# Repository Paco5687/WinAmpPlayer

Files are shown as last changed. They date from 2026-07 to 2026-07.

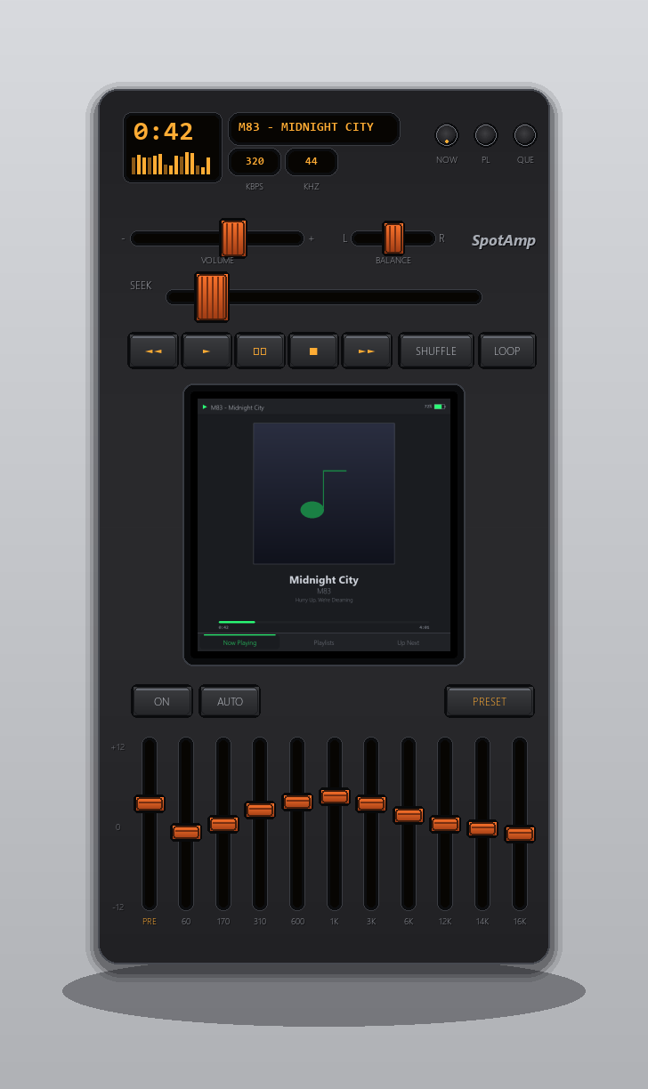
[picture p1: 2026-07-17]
docs/images/product-render-compact.png

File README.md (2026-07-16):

# WinAmp · Physical Edition

A handheld, book-sized (≈8″ × 5″ × 1″) physical Spotify player styled after the
classic WinAmp interface. Color LCD touchscreen for the playlist and album art;
everything else is **real hardware** — buttons, pots, and **motorized faders**
for a graphic EQ plus volume and a seek fader that physically follows the song.

Inspired by [Eslam Mohamed's modular WinAmp concept](https://www.yankodesign.com/2024/04/27/modular-media-player-concept-brings-iconic-winamp-design-to-the-physical-world/)
— but built as a single integrated unit, and actually real.

> *It really whips the llama's ass.*

**Open source (MIT).** Built on a **Raspberry Pi 4 B**. Code, full parts list, and
3D models are being published so you can build your own — see the
**[Wiki](https://github.com/Paco5687/WinAmpPlayer/wiki)** and
[CONTRIBUTING.md](CONTRIBUTING.md).

## Architecture at a glance

Two brains, because Linux is bad at real-time motor control and a microcontroller
is great at it:

```
        ┌───────────────────────────┐        USB serial        ┌──────────────────────┐
        │     Raspberry Pi 4 B       │◀───────(ASCII)──────────▶│  RP2040 (Pico)       │
        │                            │                          │                      │
        │  go-librespot ─▶ ALSA EQ ─▶│─▶ I2S DAC ─▶ 🎧          │  buttons / pots      │
        │        │            ▲      │                          │  encoders            │
        │  Spotify Web API    │      │   FADER <id> <pos> ──────▶  motorized faders    │
        │        │            │      │                          │   (PID position loop)│
        │  Pygame UI (this) ──┘      │◀──── EV FADER/BTN/TOUCH ──│  ← wiper ADCs (mux)  │
        └───────────────────────────┘                          └──────────────────────┘
              color LCD touchscreen
```

- **[`pi/`](pi/)** — the Python/Pygame player app. Runs **fully mocked on a
  laptop today** (no hardware, no Spotify account needed). This is where the UI
  and app logic live.
- **[`firmware/`](firmware/)** — the RP2040 firmware: reads controls, runs the
  closed-loop control for the motorized faders, speaks the serial protocol.
- **[`hardware/`](hardware/)** — bill of materials, wiring, enclosure notes.
- **[`docs/`](docs/)** — [architecture](docs/architecture.md) and the
  [serial protocol spec](docs/serial-protocol.md).

## Try it right now (no hardware)

```bash
cd pi
pip install -r requirements.txt
python -m winamp_player
```

A square (720×720) window opens with the device's **multi-view UI** — the same
screen that runs on the HyperPixel: **Now Playing**, **Playlists**, and **Up Next**.
Switch views with the bottom tabs (or keys `1`/`2`/`3`). Transport/EQ/faders are
physical hardware on the real device, not on the screen.

Keys: `1/2/3` switch views · `space` play/pause · `←/→` prev/next · `↑/↓` volume · `s` stop · `q` quit.

Requires **Python 3.11+** (uses `tomllib`).

## Status

**Standalone on a Pi 4 B and playing** — full [project board](https://github.com/users/Paco5687/projects/4).

Done:
- [x] Desktop mock app end-to-end (UI, Spotify Web API browse, playback, queue)
- [x] **go-librespot** on the Pi — standalone audio, no phone (see [docs/pi-bringup.md](docs/pi-bringup.md))
- [x] App running on the device's screen (portrait), controlling the local player

Next up:
- [ ] **Central screen redesign** — HyperPixel 4.0 Square + compact multi-view UI (now playing / playlists / queue) with physical view buttons
- [ ] RP2040 firmware: buttons, pots, encoders, motorized-fader PID
- [ ] ALSA software EQ + real FFT spectrum
- [ ] Power (USB-C UPS, battery via RP2040) and enclosure CAD

See [docs/pi-bringup.md](docs/pi-bringup.md) and per-directory READMEs for details.

## The honest hard parts

- **Spotify needs Premium + go-librespot.** There's no official "play a playlist
  on a Pi" API. go-librespot is a full Spotify client that runs on the Pi and
  authenticates **standalone — no phone** (one-time OAuth, then cached). See
  [docs/spotify-setup.md](docs/spotify-setup.md).
- **Motorized faders are the cost/complexity center.** A full motorized EQ +
  volume + seek is ~10 motorized faders (~$180+) plus motor drivers, position
  ADCs (via a mux), and a PID loop. A 10-band EQ won't physically fit a 5″ width,
  so this build uses a **7-band** EQ. See [hardware/BOM.md](hardware/BOM.md).
- **Spotify exposes no EQ**, so the graphic EQ is a software EQ in the Pi's ALSA
  pipeline, applied to go-librespot's output before the DAC.

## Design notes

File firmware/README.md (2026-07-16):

# Firmware (RP2040 / Raspberry Pi Pico)

Owns all physical I/O and the real-time motor loops for the motorized faders.
Talks to the Pi over USB serial using the [serial protocol](../docs/serial-protocol.md).

## Build

Uses [PlatformIO](https://platformio.org/) with the Arduino core for RP2040
(`earlephilhower/arduino-pico`):

```bash
cd firmware
pio run                 # build
pio run -t upload       # flash (hold BOOTSEL on first flash, or use the reset)
pio device monitor      # watch the serial link
```

## What it does

- Reads buttons (via MCP23017), encoders, the balance pot, and all fader wiper
  positions (through a CD74HC4067 analog mux, since the Pico has only 3 ADC
  channels).
- Runs a per-fader **PID loop** at ~1 kHz driving each motorized fader toward the
  target the Pi last sent (`FADER <id> <pos>`), and yields the motor while the
  user is touching that fader (MPR121 touch electrodes).
- Drives the **amber OLED readout** (SSD1322 over SPI) from `DISP` commands the
  Pi streams (title / time / stream info).
- Emits `EV …` events upstream (button presses, user fader moves, touch, encoders).

> **I/O architecture:** motor PWM goes through **2× PCA9685** and buttons/touch
> through **MCP23017/MPR121**, all on one I2C bus — direct-wiring doesn't fit the
> Pico's 26 GPIO. Full pin budget in [../hardware/wiring.md](../hardware/wiring.md).
> The `main.cpp` skeleton still drives one fader on direct pins for bring-up;
> switch to the PCA9685 when scaling past one.

The firmware is **fully built out** (desk-written 2026-07-16, compiles clean,
untested on hardware): every I2C device driver, the OLED readout with the `DISP`
marquee, buttons/encoders/touch/battery events, and the per-fader PID against
the PCA9685. `src/config.h` holds all pins, addresses, and tuning constants —
including **feature flags** (`HAS_PCA9685`, `HAS_OLED`, …) so bench bring-up can
enable one subsystem at a time. A missing I2C board logs `... MISSING` and
degrades instead of hanging.

## Bring-up order (with the full firmware)

1. Flash with **all `HAS_*` flags off except none needed** — `PING`→`PONG` over
   USB proves the link (`LOG winamp-fw ready`).
2. Enable `HAS_MCP23017` → press buttons, watch `EV BTN`. Encoders are always
   on (direct GPIO) — turn them, watch `EV ENC`.
3. Wire fader #1 (wiper → mux ch0, motor → PCA A ch0/1, touch → MPR121 e0);
   enable `HAS_PCA9685` + `HAS_MPR121`. Send `FADER 0 512` — tune `PID_KP/KD`
   and `PWM_MIN_MOVE` (stiction floor) in `config.h` until it glides.
4. Enable `HAS_OLED` — the Pi's `DISP` stream should show time + title.
5. Enable `HAS_TPA2016` + `HAS_MAX17040` — battery `EV BAT` every 5 s, jack
   insert mutes the amp.
6. Scale to all 10 faders.

⚠️ Safety built in: PCA9685 **/OE is held high (motors disabled) until the
firmware has zeroed all channels** — no fader slam on boot.

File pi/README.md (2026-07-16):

# Pi app — `winamp_player`

The Python/Pygame application: the WinAmp-style UI, Spotify control, and the
bridge to the microcontroller. Runs **fully mocked on a laptop** so you can build
the UI with no hardware and no Spotify account.

## Run (mock mode — default)

```bash
cd pi
pip install -r requirements.txt   # pygame is all you need for mock mode
python -m winamp_player
```

Requires **Python 3.11+** (uses the stdlib `tomllib`).

A square (720×720) **multi-view** window opens — the device screen: **Now Playing**,
**Playlists**, **Up Next**. On the real device these views are switched by dedicated
physical buttons; transport/EQ/faders are hardware, not on screen.

**Controls in the window (dev):**

| Input | Action |
|---|---|
| Tabs / `1` `2` `3` / `Tab` | switch view (Now Playing / Playlists / Up Next) |
| Tap a playlist row | open + play that playlist |
| `space` | play/pause |
| `←` / `→` | prev / next |
| `↑` / `↓` | volume |
| `s` | stop · `q` / `Esc` quit |

## Connect Spotify (Web API — playlists & album art)

No website or hosting needed — it uses a **loopback redirect + PKCE**.

1. Create an app at https://developer.spotify.com/dashboard.
2. Add this **exact** redirect URI (Spotify banned `localhost`; loopback HTTP is fine):
   ```
   http://127.0.0.1:8888/callback
   ```
3. Put the app's **Client ID** in `config.toml` as `spotify_client_id` (no secret needed).
4. Authorize once:
   ```bash
   python -m winamp_player.authorize
   ```
   A browser opens, you approve, and a refresh token is cached to
   `pi/spotify_token.json` (gitignored). The device refreshes tokens forever after that.

`go-librespot` (the audio playback) authenticates **separately and standalone** —
using its own one-time **interactive OAuth** login (no phone required; a phone via
Spotify Connect is only an optional alternative). It needs Premium. See
[../docs/spotify-setup.md](../docs/spotify-setup.md) for both one-time logins.

## Run against real hardware

Copy `config.example.toml` → `config.toml` and set:

```toml
backend  = "librespot"      # needs a running go-librespot + Spotify Premium
controls = "serial"         # needs the RP2040 flashed and connected
serial_port = "/dev/ttyACM0"
fullscreen = true           # on the device LCD
```

`requests` and `pyserial` (in `requirements.txt`) are only needed for real
hardware; they're imported lazily so mock mode doesn't require them.

## Layout

```
winamp_player/
├── __main__.py      # python -m winamp_player
├── app.py           # main loop, action routing, MOTOR SYNC
├── config.py        # config.toml loader (zero-config defaults)
├── models.py        # PlayerState / Track — the source of truth
├── spotify.py       # MockPlayer + LibrespotPlayer behind PlayerBackend
├── controls.py      # serial protocol + MockControls / SerialControls
└── ui/
    ├── skin.py      # palette + portrait layout rectangles
    └── display.py   # rendering + mouse/touch -> actions
```

See [../docs/architecture.md](../docs/architecture.md) for how it all fits.

## Playlist browser

Once authorized (above), the touchscreen opens on **your real Spotify
playlists** with album-art thumbnails (loaded async so the UI never blocks).
Tap a playlist → tap a track → it plays. The **eject** button (or `b`) returns
to the library. Without a token it falls back to a demo playlist.

### Playing followed playlists (`backend = "webapi"`)

Spotify Dev Mode can't *read the track list* of playlists you don't own, but it
**can play them**. So there are two playback modes (set `backend` in `config.toml`):

| `backend` | Owned playlists | Followed / editorial playlists | Audio |
|---|---|---|---|
| `mock` (default) | tracklist + simulated playback | flagged "dev-mode locked" | none (simulated) |
| `webapi` | tracklist + **real playback** | **plays** (now-playing view, no tracklist) | real, on an active device |

To use `webapi` **now**, on your laptop:
1. Set `backend = "webapi"` in `config.toml`.
2. **Open the Spotify desktop or phone app** (it becomes the "active device" to play on).
3. Run the app. Owned playlists play with a tracklist; followed playlists show a
   **now-playing** card (art, title, progress) mirrored from the real player.

On the Pi, the "active device" becomes **go-librespot** instead of the Spotify
app — same code path, no phone. If you see *"No active Spotify device,"* nothing
is available to play on yet.

### "Up Next" tracklist

In `webapi` mode the now-playing view shows an **UP NEXT** list from the Spotify
**playback queue** (`GET /me/player/queue`). This gives you a tracklist for
*anything* playing — including followed/editorial playlists whose tracks Dev Mode
won't let us read directly, and whatever's playing on another device. It shows
what's coming up (not the full playlist history).

## Notes / TODO

- **Album art** is now real (fetched + cached from the Web API in `images.py`).
  Placeholder gradient shows only until each image finishes downloading.
- **Spectrum** is simulated when no audio tap is present; on the Pi, feed real
  FFT magnitudes into `PlayerState.spectrum`.
- **EQ** currently just stores band gains; the ALSA software-EQ pipeline that
  applies them is milestone M5 (see architecture roadmap).

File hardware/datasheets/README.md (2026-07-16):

# Datasheets

Run `bash fetch.sh` in this directory to download every part's datasheet /
mechanical drawing (~26 MB). **The PDFs are gitignored** — they're manufacturer
copyright, so the repo ships the script + this index instead of the files.

## Index + key facts for case design

| File | Part | Key mechanical / electrical facts |
|---|---|---|
| `alps-rs60n-motorized-fader.pdf` | ALPS RS60N11M9A0F | ⚠️ **Body 18.5 mm wide** (min pitch ~19–20 mm), **26 mm deep below panel**, mounting 2× M3, lever 8.2 mm above panel, motor **rated 10 V DC / ≤800 mA**, travel 60 mm, touch-sense track. See [../enclosure.md](../enclosure.md) for the layout consequences. |
| `pca9685-pwm-driver.pdf` | NXP PCA9685 | 16-ch 12-bit PWM, I2C (up to 62 addrs), ~24–1526 Hz PWM |
| `mpr121-cap-touch.pdf` | NXP MPR121 | 12 electrodes, I2C 0x5A–0x5D |
| `mcp23017-gpio-expander.pdf` | Microchip MCP23017 | 16 GPIO, I2C 0x20–0x27, interrupt outs |
| `cd74hc4067-mux.pdf` | TI CD74HC4067 | 16:1 analog mux, ~70 Ω on-resistance |
| `drv8833-motor-driver.pdf` | TI DRV8833 | dual H-bridge, 2.7–10.8 V, 1.5 A RMS/bridge |
| `tpa2016-speaker-amp.pdf` | TI TPA2016D2 | stereo Class-D 2.8 W@4Ω/5 V, I2C 0x58, AGC, shutdown |
| `ws2812b-led.pdf` | WS2812B | 800 kHz single-wire, 5 V |
| `pico-datasheet.pdf` / `pico-pinout.pdf` | Raspberry Pi Pico | board 51 × 21 mm, pin functions |
| `pi4-mechanical-drawing.pdf` | Pi 4 B | board 85 × 56 mm, port + hole positions |
| `pi4-reduced-schematics.pdf` | Pi 4 B | connector-level schematics |
| `bourns-pec11-encoder.pdf` | Bourns PEC11 (= Adafruit 377) | panel hole ⌀7 mm, shaft dims |
| `ssd1322-oled-controller.pdf` | SSD1322 | controller registers/commands (firmware) |
| `nhd-3.12-25664-oled-module.pdf` | NHD-3.12-25664UCY2 | module ≈ 88 × 27.8 mm (verify drawing page), 4-wire SPI |

## HTML-only references (no stable PDF)

- **Geekworm X728**: https://wiki.geekworm.com/X728 — HAT form (~85 × 56 mm) +
  pogo/header stack height; schematic + safe-shutdown scripts on the wiki.
- **HyperPixel 4.0 Square**: https://shop.pimoroni.com/products/hyperpixel-4-square —
  ~85 × 85.5 × 12 mm per product page (verify before cutting the bezel).
- **ALPS 3D CAD (STEP)** for the fader is downloadable from the ALPS product page —
  grab it when starting CAD: https://tech.alpsalpine.com/e/products/detail/RS60N11M9A0F/

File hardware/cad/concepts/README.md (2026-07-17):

# Layout concepts (exploration — not the authoritative drawing)

**concept-e — CURRENT FRONT-RUNNER (185 × 295 mm)**: the owner's sketch at A's
proportions. **The screen is the centerpiece** (engraved accent frame, floated
in open space); quiet right strip (speaker grille + 2×2 pots); view-key stack
top-right; 6-button transport; LOOP/EQ/PRESET function row + encoders + balance;
full-width seek; **A's 8 faders unchanged**, spread at 21 mm pitch. Pure layout —
zero BOM/firmware/I/O change from A. Pending 1:1 paper test → replaces mainline.

**concept-d — the owner's sketch (220 × 280 mm)**: OLED top-left, **view-key
stack top-right**, 6-button transport row (+SHUF), full-width volume, function
row (LOOP/EQ/PRESET keys + encoders + balance), **screen left**, speaker grille
field + 2×2 pot cluster right, seek right-side (kept — the signature fader; the
sketch omitted it), and the **full 10-band + preamp EQ** across the bottom.
Current front-runner pending 1:1 paper test.

**concept-c — "the in-between" (220 × 280 mm)**: the vibe-keeper. Screen stays
**centered** (classic stacked-module composition), full **10-band EQ + preamp**,
and **symmetric stereo grille fields** flanking the screen (L/R where stereo
wants them). No pot column. Button columns cleared of the HyperPixel board edge
(3D check). Owner feedback path: A = vibe but 7-band · B = 10-band but vibe lost
· **C = both**.

**concept-b** (225 × 280 mm): screen offset left, right-hand pot column
(HP-vol / brightness / 2 assignable), one large speaker-grille field, and the
**full classic 10-band EQ + preamp** (11 motorized faders). Generated from a
variant of [`../generate_panel.py`](../generate_panel.py); if chosen, the
variant becomes the main generator's parameters and this folder is cleaned up.

I/O check at 11 faders: 22/32 PCA9685 PWM · 11/12 MPR121 electrodes · 14/16 mux
channels — fits the existing architecture. Cost delta ≈ +$65–70.

Print the SVG at 100 % scale for the paper test (same as the main panel).

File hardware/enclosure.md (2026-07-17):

# Enclosure design notes

The case will be **3D-printed for the prototype** and, if it earns it,
**CNC-machined in anodized aluminum** for the final build. Every enclosure
decision must work for **both** processes — design for machining from day one,
print the same geometry.

## ⚠️ Findings from the real datasheets (2026-07-16)

Reading the ALPS RS60N11M9A0F drawing (see [datasheets/](datasheets/)) surfaced
three facts that change the body:

| Finding | Consequence |
|---|---|
| Fader body is **18.5 mm wide** → min pitch ~19–20 mm | An 8-fader bank needs **~155 mm**, but the panel is 127 mm. **The 7-band + preamp bank does not fit a 5″ width.** Options below. |
| Fader is **26 mm deep below the panel** | Body thickness grows from 25 mm to **~32 mm (1.25″)** (panel + 26 + wiring clearance), or the fader zone gets a raised rear bulge. |
| Fader motor rated **10 V / ≤800 mA** | On our 5 V rail the slew is slower/weaker (workable, common in DIY). Optional: a small 9 V boost for the motor rail. Bench-test with fader #1 before deciding. |
| **Fader body is ~106.5 mm LONG (M3 mounts 80 mm apart)** — found drawing the DXF | A *vertical* EQ fader needs ~110 mm of panel height, not the ~66 mm sketched earlier. The honest full stack (top module + volume + 73 mm screen + seek + EQ bank) sets the panel at **175 × 280 mm (6.9″ × 11″)** — which matches the Yanko render's real proportions. The laid-out proof: [cad/front-panel.dxf](cad/). |

### EQ-bank width options (decision pending)

| Option | Panel math | Trade-off |
|---|---|---|
| **A. Widen the body to ~165 mm (6.5″)** | 8 × 20 = 160 ✓ | keeps all 7 bands + preamp motorized; body is no longer "small book" |
| **B. 5 bands + preamp** | 6 × 20 = 120 ✓ fits 127 | fewer bands; protocol/firmware are per-band so it's a config change |
| **C. Reduced build** (motorized volume + seek only, slim non-motorized pots for EQ) | narrow pots ~10 mm pitch ✓ | loses the animated-EQ showpiece |

> **Current direction (2026-07-17, pending 1:1 print approval): the ONE-MOTOR
> design — 127 × 246 × ~30 mm** (`cad/front-panel-final.*`). EQ/volume/balance
> use slim non-motorized pots (full classic PRE + 10-band bank fits the beloved
> 127 mm width); **seek keeps the single motorized RS60N** (song-tracking
> showpiece). Yanko-faithful details: 4 sculpted apertures over the one OLED,
> WinAmp stack order, ON/AUTO/PRESET EQ header, ribbed caps, recessed wells.
> Electronics collapse: no PCA9685s, 1× DRV8833, ~−$220. The earlier 175 × 280
> all-motorized drawing (`cad/front-panel.*`) is superseded on approval.

## Design-for-machining rules (apply from the first CAD sketch)

1. **Two flat-dominant halves**: front panel (all cutouts) + rear tray (cavity).
   Both machinable from plate stock on a 3-axis mill; both printable flat.
2. **Internal corner radii ≥ 2 mm** everywhere a cutter must reach (an end mill
   can't cut a sharp inside corner). Exterior corners can be sharp or chamfered.
3. **No snap-fits, no living hinges, no print-in-place** — those are FDM-only.
   Fasten with **machine screws from the rear** into bosses: heat-set inserts in
   the printed version, **drilled + tapped** in aluminum (M3, ≥6 mm thread).
4. **Wall thickness ≥ 2 mm** (aluminum) / ≥ 2.4 mm (FDM, 6 perimeters at 0.4 mm).
5. **Through-cutouts are cheap in both processes** (fader slots, screen window,
   button holes, OLED window). **Deep pockets** with small tools are expensive —
   keep pocket depth ≤ 4× tool diameter where possible.
6. **Anodizing allowances**: type II adds ~5–10 µm/surface (negligible), but
   **mask or re-tap threads after anodizing** (anodized threads gall);
   bead-blast before anodize for the matte look. Black or clear both look right;
   colored fill on engraved labels is an option (engrave → anodize → fill).
7. **Labels**: engrave (V-bit or laser) rather than print/silkscreen — works on
   both plastic and aluminum, and survives handling.
8. 📡 **Wi-Fi in an aluminum box does not work.** The Pi's antenna will be
   completely shielded. Plan one of:
   - a **plastic antenna window** (the screen bezel area can be polymer trim),
   - the **kickstand slot / speaker grille** doubling as an RF aperture near the
     Pi's antenna corner,
   - or an **external/relocated antenna** (Pi 4 antenna mod is invasive — prefer
     the window). The FDM prototype hides this problem; **test Wi-Fi with the
     aluminum rear tray fitted** before finalizing.
9. **Serviceability**: the fader bank should mount to the panel with its M3
   screws (per the ALPS drawing: 2× M3 per fader, mounting-hole pattern in the
   datasheet) so a failed fader is replaceable without disassembling the stack.
10. **Thermals**: Pi 4 + motor drivers in a sealed metal box is actually *good*
    (the case is the heatsink) — add a thermal pad from the Pi SoC to the rear
    tray in the aluminum version; the printed version needs vent slots instead.

## Reference dimensions for CAD

| Component | Envelope | Source |
|---|---|---|
| ALPS RS60N fader | 18.5 w × ~88 l × 26 mm below panel; lever +8.2 mm | datasheet drawing |
| HyperPixel 4.0 Square | ~85 × 85.5 × 12 mm | product page (verify) |
| Pi 4 B | 85 × 56 mm, holes 58 × 49 mm grid | `pi4-mechanical-drawing.pdf` |
| X728 UPS | HAT: 85 × 56 mm + 18650 holders | wiki.geekworm.com/X728 |
| Pico | 51 × 21 mm | `pico-datasheet.pdf` |
| OLED module | ≈ 88 × 27.8 mm | NHD spec (verify) |

## Speakers (added 2026-07-16 — standalone playback, headphones optional)

- **Drivers**: enclosed stereo pair, **70 × 30 × 17 mm each** (sealed backs — no
  custom acoustic chamber needed; they just bolt in). Fits the 32 mm depth.
- **Placement**: side edges of the top module firing outward, or flanking the
  screen — decide in CAD around the fader bank. Keep them away from the
  HyperPixel's rear (magnet clearance) and off the fader axis (vibration).
- **Grilles**: a drilled hole pattern looks *great* in anodized aluminum and is
  trivially machinable (≥1.5 mm holes, ≥2× diameter spacing). The FDM version
  prints the same pattern.
- **Headphone jack**: panel-mount switched TRS; insertion detect → MCP23017
  spare input → firmware mutes the TPA2016 over I2C. Jack near the bottom edge
  (cable hangs naturally when handheld).
- **Vibration**: mount drivers on thin foam gaskets so the aluminum panel
  doesn't buzz at volume.
- **Loudness upgrade slot (decided 2026-07-16)**: v1 ships the TPA2016; the CAD
  reserves space for a **MAX9744 (I2C, same bus) + 5→12 V boost** and grille area
  for ~2″/5 W drivers — the "small boombox" tier is a one-board swap after bench
  listening, no redesign.

## Kickstand (added 2026-07-17 — this is a DESKTOP device)

Per the concept's pop-out stand: the device lives on a desk, leaning back —
portable between rooms, not pocket-portable. Design decisions:

- **Type**: a flat **fold-out leg** hinged across the rear at the EQ-module
  height (lower third), Surface-style. In aluminum it's a machined flat plate —
  looks fantastic anodized; on the prototype it's the same geometry printed.
- **Hinges**: 2× **adjustable-torque (position-control) hinges** so the angle is
  continuously adjustable and holds anywhere (~$6–12 ea). Cheaper fallback: a
  plain piano hinge + a fold-out wire strut into detent notches (two angles).
- **Angle range**: 0° (flush) to ~40° open → face angle ~70–80° from the desk,
  matching the render and comfortable for fader reach + screen viewing.
- **Tip resistance — the physics that matters**: users *push* faders and buttons
  (1–3 N) near the top of a 280 mm face. The leg tip must land **well behind the
  center of mass** (leg ≥ 120 mm long), with **rubber feet on the leg tip and the
  body's bottom edge**. The battery pack (the heaviest part) mounts LOW in the
  body — it's the counterweight.
- **Flush stowage**: the rear tray gets a **recessed pocket** so the closed leg
  sits flush (machinable pocket — large corner radii; printable as-is). A small
  **magnet + steel disc** holds it closed with a satisfying snap.
- **Don't-block list**: the leg (open or closed) must not cover the USB-C charge
  port, the power switch, the thermal-pad zone (rear tray = heatsink), or the
  **Wi-Fi antenna window** — place the pocket accordingly in CAD.
- The rear tray + stand get their own generated drawing when we do the body CAD
  (the parametric generator extends to it — same source of truth as the panel).

## The OLED aperture cluster (how the "multiple displays" work)

One 256×64 OLED sits behind **four sculpted apertures** (time+spectrum window,
title strip, two kbps/kHz pills) — the panel mask turns one display into four.
Implementation notes:
- The apertures must land inside the OLED's **76.78 × 19.18 mm active area**;
  positions in `cad/generate_panel.py` are derived from it. Mask alignment
  tolerance ±0.5 mm — locate the OLED with pins/bosses, not adhesive guesswork.
- Put a **smoked/amber acrylic layer** (~1 mm) behind the apertures so off
  pixels vanish into black and the windows read as separate lit instruments.
- Firmware renders each element at fixed pixel regions matching the mask (the
  `DISP` data already carries everything; the region map is a table in
  `firmware/src/config.h` when formalized).

## The seek mechanism (owner's design, 2026-07-17): custom belt drive

Off-the-shelf motorized faders package the motor IN-LINE with the track — the
RS60N wastes 46 mm of length beyond its travel, and the 100 mm RSA0N is 146.5 mm
long. **We build the drive ourselves instead** (this is how flying faders work
internally anyway):

- **Panel part**: a slim **manual long-travel slide pot** (~85–90 mm travel,
  body ≤ 118 mm — VERIFY candidate part) → the slot spans ~70 % of the face at
  the 127 mm width. Wiper = position feedback (mux, as always); metal knob =
  touch electrode (MPR121).
- **Drive**: micro gearmotor (N20-class) + 2× GT2 16T pulleys + a GT2 belt loop
  behind the panel, with a printed clamp tying the belt to the fader lever — a
  miniature 3D-printer axis. Motor mounts beside/behind; envelope ~120 × 14 mm
  (REF box in the cut drawing).
- **Electronics/firmware unchanged**: DRV8833 + the existing PID loop drive it
  identically to a packaged motorized fader.
- ⚠️ **The critical detail — backdrivability**: the user must be able to grab
  the fader anytime. High-ratio gearmotors lock. Prototype in this order:
  (1) **slip-clutch pulley** — printed friction hub on the motor pulley (what
  ALPS does internally); (2) low-ratio (≤30:1) or coreless motor that
  backdrives freely; (3) touch-triggered release as backup. **Bench-prove the
  clutch before committing the panel.**
- Benefits: −$20 ALPS fader → +~$15 of motor/belt/pulleys, every mechanical
  part printable now and machinable later, and the seek slot finally matches
  the concept's proportions.

### Why output-side sensing (and not a servo indicator)

Considered and rejected (2026-07-17): a servo-driven progress pointer ("the
motor knows the position"). Three reasons the pot-on-the-knob topology wins:
1. **The pot measures the actual knob** — belt slip is cosmetic and
   self-correcting (PID drives until the *output* arrives). A servo knows only
   its motor-side pot; a loose linkage lies with no sensor to catch it.
2. **Touch-gating means motor motion can never seek the song** — position
   events only fire while the MPR121 senses a grab. The song clock lives in
   go-librespot; the fader follows it, not vice-versa.
3. **Servos aren't back-drivable** — grab-to-scrub (the whole point) dies.

**De-risk path**: the panel is identical with or without the motor — if the
slip-clutch prototype disappoints, v1 ships seek as a manual-scrub fader and
the belt drive lands in v1.1 with zero panel changes.

## Knobs & finish

- **Final build**: aluminum fader caps (T-bar or rectangular, for the ALPS 9-T
  lever) + knurled aluminum encoder knobs, anodized to match or contrast the body.
- **Prototype**: 3D-print the same knob geometry so the CAD is shared — print to
  fit, then order/machine the aluminum versions from the identical model.
- Fader caps must clear adjacent slots at 20 mm pitch — cap width ≤ 16 mm.

Grab the **ALPS STEP model** from the product page when CAD starts — it's the
part everything else packs around.

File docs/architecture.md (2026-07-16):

# Architecture

## Why two brains

The Pi runs Linux, which is non-deterministic under scheduling load — fine for
UI and networking, bad for a tight motor-control loop that has to run at a
steady ~1 kHz to keep motorized faders from oscillating. So:

- **Raspberry Pi** — Spotify client, audio pipeline, the LCD UI, high-level
  logic. Sends *targets* ("move volume fader to 72%").
- **RP2040 microcontroller** — soft-real-time I/O. Owns the PID loops that drive
  each motorized fader to its target, debounces buttons, reads pots/encoders,
  and streams events up to the Pi.

They talk over a simple newline-delimited ASCII protocol on USB serial. See
[serial-protocol.md](serial-protocol.md).

## Alternative platforms (future / v2)

The **[Arduino Uno Q](https://docs.arduino.cc/hardware/uno-q/)** is architecturally
this exact design on a single board: a Qualcomm Dragonwing QRB2210 (quad
Cortex-A53, runs Debian Linux) **plus** an STM32U585 (Cortex-M33) real-time MCU,
with an internal bridge — i.e. our "Pi brain + RP2040 brain" fused, plus eMMC.

We're **staying on Pi 4 B + RP2040 for v1** because: the Uno Q's MIPI-DSI display
and analog audio come out only via a separate carrier board; it's brand-new
(Oct 2025) with an unproven ecosystem/supply — risky for a build others must
reproduce; and we already have a working Pi stack. It's a strong **v2 candidate**
if its ecosystem matures — it could collapse both boards into one.

## Audio path

```
Spotify ──▶ go-librespot ──▶ ALSA (software graphic EQ) ──▶ USB DAC ──▶ switched 3.5mm jack
                                    ▲                  │                     │ (no plug)
                          EQ gains from faders         │              TPA2016 amp ──▶ internal
                                                       │             (I2C, RP2040 bus)  speakers
                                          audio tap ──▶ FFT ──▶ spectrum bars (UI)
```

> The DAC is **USB** (not a GPIO I2S HAT) because the HyperPixel display's DPI
> interface consumes all 40 GPIO pins, including I2S. The Pi's 3.5 mm jack works
> for bring-up. **Standalone playback** comes from internal enclosed speakers via
> a TPA2016 Class-D amp; inserting headphones mutes the amp (jack detect →
> firmware). External outputs are software: **Spotify Connect transfer** (Sonos &
> co. via the Web API — no audio plumbing) and **Bluetooth A2DP** from the Pi 4's
> onboard radio.

- **go-librespot** is a full Spotify client that streams and decodes audio
  directly (requires Premium). It authenticates **standalone via interactive
  OAuth** — a one-time browser login, then it reconnects on cached credentials
  forever, no phone. It exposes an HTTP + WebSocket API for transport and
  now-playing metadata. (Zeroconf/"pick it from a phone" is an optional mode we
  don't rely on.)
- The **graphic EQ is ours** — Spotify exposes no EQ over the API, so we insert a
  software EQ into the ALSA chain (e.g. an `ladspa`/`caps` multi-band plugin, or
  a custom filter). The motorized EQ faders set its band gains.
- A **loopback/monitor tap** feeds a small FFT so the spectrum analyzer reflects
  the actual audio, not a simulation. (In mock mode it's simulated.)

## The Pi app (`pi/winamp_player/`)

| Module | Responsibility |
|---|---|
| `models.py` | `PlayerState`, `Track` — the single source of truth the UI renders |
| `spotify.py` | `MockPlayer` (simulation), `WebApiPlayer` (drive any Connect device), `LibrespotPlayer` (the on-device player) behind one `PlayerBackend` interface |
| `spotify_web.py` / `spotify_auth.py` | Web API client (playlists, queue, control) + loopback-PKCE auth |
| `library.py` / `images.py` / `power.py` | Async playlist browsing, album-art cache, battery sources |
| `controls.py` | Serial protocol + `MockControls` / `SerialControls` |
| `ui/skin.py` | Palette + shared drawing helpers |
| `ui/screen.py` | Compact **multi-view** screen UI (Now Playing / Playlists / Queue) for the square LCD; turns touch/buttons into actions |
| `app.py` | Main loop, action routing, and **motor sync** |

### Motor sync — the signature trick

Every frame, `app._sync_motors()` computes where each motorized fader *should*
be from `PlayerState` (volume, seek progress, EQ band gains) and sends a
`FADER <id> <pos>` target — **unless the user is currently touching that fader**
(tracked via `EV TOUCH` events). So:

- Change the song → the **seek fader glides** to the new position and tracks it.
- Load an EQ preset → the **EQ faders physically animate** into the curve.
- Grab a fader → the motor yields; when you let go, it holds your value.

### Backend abstraction

`PlayerBackend` is a `Protocol`. `MockPlayer` advances a demo playlist with no
network so the entire UI is buildable on a laptop. `LibrespotPlayer` maps the
same methods onto go-librespot's local HTTP API (the on-device path);
`WebApiPlayer` drives any active Spotify Connect device through the Web API
(useful for laptop dev with real audio). Swap via `config.toml`.

## Central screen & UI direction

The device is **physical-first**: transport, EQ, and faders are hardware; the
screen is a small **square** LCD (**HyperPixel 4.0 Square, 720×720**) showing the
compact **multi-view** UI in `ui/screen.py` — one view at a time, switched by
**dedicated physical buttons** (ButtonId 9–11 in the serial protocol; on-screen
tabs and keys `1`/`2`/`3` in dev). v1 views: Now Playing, Playlist selector, Play
Queue (Search later). Playback control uses `backend = "librespot"`
(go-librespot's local API on :3678), so control stays on the Pi — no cloud
round-trip. The HyperPixel's DPI takes all GPIO, so audio → USB DAC and battery
sensing → RP2040 (see hardware/BOM.md).

## Deployment on the Pi

The full, tested procedure is **[pi-bringup.md](pi-bringup.md)**. In short:

1. `go-librespot` as a systemd service, authenticated once via interactive
   OAuth (standalone; see [spotify-setup.md](spotify-setup.md)).
2. HyperPixel 4.0 Square via the `vc4-kms-dpi-hyperpixel4sq` overlay; rotation
   done at the **compositor** level so touch follows the display.
3. The UI as a systemd **user** service (kiosk): boots straight into the app,
   fullscreen, cursor hidden (`deploy/winamp-kiosk.*`).
4. *(Phase 4)* ALSA EQ between librespot and the USB DAC.
5. *(Phase 5)* RP2040 flashed and enumerated at `/dev/ttyACM0`.

## Roadmap

Tracked live on the **[project board](https://github.com/users/Paco5687/projects/4)**
(milestones Phase 1–9 plus "UI Redesign & Central Screen"). Done so far: desktop
mock, Spotify integration (auth/browse/playback/queue), standalone audio on the
Pi, HyperPixel + kiosk autostart, the multi-view screen UI. Next up:
playlist-detail view + list scrolling, RP2040 physical controls, motorized
faders, software EQ + real spectrum, power/battery, enclosure.

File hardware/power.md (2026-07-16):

# Power & Battery Design

The unit is handheld, so it runs from an internal battery with a regulated 5 V
rail, safe charging, battery monitoring, and a clean shutdown that protects the
SD card. This document sizes the system, recommends a topology that's easy for
others to replicate, and lists the tradeoffs.

> Status: **design + placeholders.** Cell counts, runtimes, and part choices are
> engineering estimates — verify against the specific boards/cells you buy.

## 1. Power budget

Measured/typical draw on a **Raspberry Pi 4 B** based system. Motors are the
spiky load — they only draw current *while moving*, and our firmware cuts motor
power once a fader reaches its target, so the holding current is ~0.

| Subsystem | Typical | Peak | Notes |
|---|---:|---:|---|
| Pi 4 B (app + Wi-Fi + audio) | 4.5 W | 7 W | 4 cores + USB busy |
| 4″ DSI/HDMI LCD + backlight | 1.2 W | 2 W | backlight dominates |
| I2S DAC + headphones | 0.3 W | 0.5 W | |
| speaker amp (TPA2016, internal stereo) | 1 W | 3 W | standalone playback; ~0 W with headphones (amp muted) |
| RP2040 + mux + LEDs | 0.4 W | 1 W | |
| Motorized faders (10×) | ~0.2 W avg | **~12–15 W** | brief spikes when several move at once |
| **System** | **~6.5 W avg** | **~20 W peak** | design the 5 V rail for **5 A** headroom |

Key takeaways:
- **Average ≈ 6.5 W.** That's what sets runtime.
- **Peaks to ~20 W** for <1 s when a preset loads and many faders slew together.
  The 5 V regulator must survive that; handle it with **bulk capacitance
  (1000–2200 µF) at the motor-driver rail** so spikes come from the caps, not the
  battery/regulator.

## 2. Recommended topology

For a project other people will replicate, favor a **safe, off-the-shelf,
monitored** solution over a hand-rolled pack:

```
 18650 Li-ion cells ─▶ UPS/BMS HAT ─▶ regulated 5 V (up to 5 A) ─▶ Pi 4 B + everything
        ▲                   │  │
   USB-C / DC charge ───────┘  └── I2C: battery %, voltage, AC-loss  ─▶ Pi (safe shutdown + UI meter)
```

**Baseline:** a Pi-oriented UPS HAT that takes 18650 cells, outputs a solid
5 V/5 A, and reports battery state over I2C — e.g. **Geekworm X728** (2×18650,
auto power-on, AC-loss detect, documented safe-shutdown scripts) or **Waveshare
UPS HAT (B)** (2×18650, 5 V/5 A, INA219 fuel gauge). Verify current model numbers
and Pi 4 compatibility before buying — SKUs churn.

Why a HAT and not a bare pack: you get **cell protection, a proven 5 V boost
rated for Pi 4 peaks, charge management, and I2C monitoring** in one board — the
hard, safety-critical parts done right.

**Decision (v1): Geekworm X728.** Its MAX17040 fuel gauge (I2C `0x36`) is what
`pi/winamp_player/power.py` (`X728Battery`) reads for the on-screen meter and
safe shutdown; it has documented shutdown scripts and AC-loss detection. Waveshare
UPS HAT (B) remains a drop-in alternative — swap the reader class if you use it.
For more runtime, feed a larger 18650 pack (4–6 cells) to the board's terminals.

## 3. Sizing the battery ("large" is the goal)

18650 cell ≈ 3500 mAh @ 3.6 V ≈ **12.6 Wh** raw. After boost efficiency (~90 %)
and a safe depth-of-discharge (~85 %), figure **~9.6 Wh usable per cell**. At the
~6.5 W average:

| Pack | Raw Wh | Usable Wh | Runtime @6.5 W | Notes |
|---|---:|---:|---:|---|
| 2 × 18650 | 25 | ~19 | **~3 h** | fits a 2-cell HAT; thin |
| 4 × 18650 | 50 | ~38 | **~6 h** | sweet spot for "large" |
| 6 × 18650 | 76 | ~58 | **~9 h** | needs a bigger body/pack |
| 8 × 18650 | 101 | ~77 | **~12 h** | ⚠ **>100 Wh = no airline carry-on** |

For "large batteries," target **4–6 cells**. Options to get there:
- a **4-cell UPS board**, or
- an **external 2S2P / 2S3P 18650 pack** wired to the HAT's cell terminals, or
- higher-capacity cells (Molicel P28A, Samsung 35E, LG MJ1).

**Airline note:** keep total under **100 Wh** if the device should be flyable;
loose spare cells have their own carry-on rules.

## 4. Cells: 18650 vs LiPo pouch (a real form-factor tradeoff)

| | 18650 Li-ion | LiPo pouch |
|---|---|---|
| Shape | cylindrical Ø18 × 65 mm | flat, custom W×H, thin |
| Fit in a 1″ (25 mm) body | tight next to 60 mm faders | **better** — lies flat |
| Safety / replaceability | **excellent**, standardized, swappable | fussier, needs careful protection |
| Best for | a shareable, safe DIY build | a genuinely thin body |

**Recommendation:** default to **18650** for safety and replaceability (this is a
public build others will copy). If you insist on the slim 1″ book profile, a
**flat LiPo pouch + a good 2S BMS + 5 V buck** is mechanically nicer — but note
that **a large battery may push the body past 1″**; faders already want ~20 mm of
depth, and an 18-mm cell beside them is tight. Call this out in the enclosure CAD.

## 5. Charging

- Charge over the HAT's **USB-C (or DC) input**; the UPS provides pass-through so
  the unit can run while charging.
- Charge current is typically **1–2 A** — a big 4–6 cell pack will take **several
  hours** to fill. If that's annoying, pick a board/charger that supports higher
  charge current and use a capable USB-PD supply.
- **Never** charge unbalanced multi-cell packs without a balancing BMS.

## 6. Safe shutdown + battery UI (software milestone)

The UPS HAT exposes battery voltage / state-of-charge over **I2C**. The Pi should:
1. Read SoC periodically (INA219 / fuel gauge / board's ADC).
2. Show a **WinAmp-style battery meter** on the LCD (a natural fit for the skin).
3. On **low battery** (~5 %) or **AC-loss + threshold**, trigger a clean
   `shutdown` so the SD card isn't corrupted.

Planned code: `pi/winamp_player/power.py` (battery monitor) + a battery widget in
the UI. *Placeholder for now* — implement once the specific UPS board is chosen,
since the I2C register map is board-specific.

## 7. Grounding & wiring notes

- Join **motor ground** and **logic ground** at a single star point near the
  regulator; H-bridges inject noise.
- Put the **bulk caps physically at the DRV8833 rails**, not near the Pi.
- Fuse the battery output; add a physical **power switch** on the 5 V rail (or use
  the HAT's soft-power button + auto-boot).
- Keep motor-current wiring short and thick; keep it away from the audio/DAC lines
  to avoid whine.

## 8. Open questions / TODO

- [ ] Pick the exact UPS board (2- vs 4-cell) and confirm 5 V/5 A + I2C monitoring.
- [ ] Decide 18650 vs LiPo once the enclosure thickness is locked.
- [ ] Bench-measure real average draw (esp. motor duty cycle) to firm up runtime.
- [ ] Implement `power.py` + battery meter + safe-shutdown against the chosen board.
- [ ] Verify total Wh vs the airline limit if portability matters.

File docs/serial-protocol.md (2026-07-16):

# Serial protocol (Pi ⇄ RP2040)

A deliberately simple, human-readable, newline-delimited ASCII protocol over USB
serial (CDC-ACM). ASCII because you can debug the whole thing with a serial
monitor. **115200 baud, 8N1.** Every message ends with `\n`.

The Python side is `pi/winamp_player/controls.py`; the firmware side is
`firmware/src/main.cpp`. Keep both in sync with this document.

## Pi → microcontroller (commands)

| Command | Meaning |
|---|---|
| `FADER <id> <pos>` | Drive motorized fader `id` to position `pos` (0–1023). Engages the PID loop toward that target. |
| `FADER_RELEASE <id>` | Cut motor power on fader `id` so the user can move it freely. |
| `LED <index> <r> <g> <b>` | Set indicator LED color (0–255 each). |
| `DISP TITLE <text>` | Scrolling title line on the amber OLED readout (single line; sent on track change). |
| `DISP TIME <pos_ms> <dur_ms>` | Elapsed/total time for the OLED (sent ~1/s). |
| `DISP INFO <kbps> <khz>` | Stream info readout (bitrate / sample rate). |
| `PING` | Liveness check; expects `PONG`. |

## Microcontroller → Pi (events)

All events are `EV <TYPE> <id> <value>`:

| Type | `value` | Meaning |
|---|---|---|
| `EV BTN <id> <0\|1>` | 1 = pressed, 0 = released | Button state change (debounced). |
| `EV FADER <id> <0..1023>` | ADC position | A fader was moved **by the user** (only sent while touched/released, not while the motor is driving it). |
| `EV TOUCH <id> <0\|1>` | 1 = grabbed | User is touching a motorized fader. The Pi stops driving it until `0`. |
| `EV ENC <id> <±delta>` | signed detent count | Rotary encoder moved. |
| `EV POT <id> <0..1023>` | ADC value | Potentiometer moved (0 = balance). |
| `EV BAT 0 <0..1000>` | state-of-charge ×10 | Battery SoC from the X728's MAX17040 (on the RP2040 I2C bus), every ~5 s. |
| `EV CHG 0 <0\|1>` | 1 = on AC/charging | X728 power-loss-detect line. |
| `EV JACK 0 <0\|1>` | 1 = headphones in | Jack insertion. Firmware mutes the speaker amp itself; informational for the UI. |

Plus out-of-band: `PONG` (reply to `PING`) and `LOG <text>` (firmware debug,
ignored by the parser).

## IDs

**Faders** (`FaderId` in `controls.py`):

| id | fader | motorized |
|---|---|---|
| 0–6 | EQ bands (60, 150, 400, 1k, 2.4k, 6k, 15k Hz) | ✅ |
| 7 | Preamp | ✅ |
| 8 | Volume | ✅ |
| 9 | Seek (tracks song position) | ✅ |

**Buttons** (`ButtonId`): 0 prev · 1 play · 2 pause · 3 stop · 4 next ·
5 eject (spare) · 6 shuffle · 7 repeat · 8 eq-on/off · **9 view:now-playing ·
10 view:playlists · 11 view:queue** (the dedicated view-switch buttons for the
central screen) · 12 eq-preset (cycles presets; the motorized faders animate
into each curve) · **13/14 encoder push switches**.

**Pots** (`PotId`, via `EV POT`): 0 balance (L/R, non-motorized).

## Example exchange

```
→ PING
← PONG
← EV TOUCH 8 1            # user grabbed the volume fader
← EV FADER 8 742          # ...and moved it
← EV TOUCH 8 0            # let go
→ FADER 9 512            # Pi: glide the seek fader to 50% (new track)
← EV BTN 4 1             # user pressed NEXT
→ FADER 9 0             # Pi: seek fader back to start
```

## Design notes

- **Idempotent targets.** The Pi resends a fader target only when it changes
  (see `App._last_sent`), so the link stays quiet at idle.
- **User wins.** While a fader reports `TOUCH 1`, the Pi never fights it. This is
  what makes the motorized feel right.
- **Framing.** One message per line. The firmware ignores unknown verbs; the Pi
  ignores unparseable lines. Forward-compatible by construction.
- **Future:** if ASCII bandwidth ever bottlenecks (it won't at these rates),
  switch to a COBS-framed binary packet with the same semantics.

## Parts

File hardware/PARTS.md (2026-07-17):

# Parts List (vendor shopping list)

The buyable version of [BOM.md](BOM.md) — real SKUs, grouped by vendor,
**Adafruit-first** where they stock it. Prices are USD as checked **2026-07-16**
(spot-verified where marked ✓; others are recent typicals — confirm at checkout).

Datasheets for everything here: run [`datasheets/fetch.sh`](datasheets/) and see
[datasheets/README.md](datasheets/README.md).

## Already owned ✅

| Part | Note |
|---|---|
| Raspberry Pi 4 B | running the player today |
| Pimoroni HyperPixel 4.0 Square | mounted + working |
| microSD 32 GB | flashed |

## 🛒 Adafruit (one cart)

| Part | SKU | Qty | ~$ ea | ~$ | For |
|---|---|---|---|---|---|
| 12-key capacitive touch (MPR121) | [1982](https://www.adafruit.com/product/1982) | 1 | 7.95 | 7.95 | seek-knob touch electrode (1 ch used) |
| MCP23017 GPIO expander breakout | [5346](https://www.adafruit.com/product/5346) | 1 | 5.95 | 5.95 | 13 panel buttons |
| DRV8833 dual motor driver breakout ✓ | [3297](https://www.adafruit.com/product/3297) | 1 | 5.95 | 5.95 | the ONE seek motor (direct Pico PWM — no PCA9685s in the build) |
| Raspberry Pi Pico | ⚠️ **OOS at Adafruit (all variants, 2026-07)** — Micro Center/PiShop/Amazon ~$4 | 1 | 4.00 | 4.00 | controls brain |
| USB audio adapter (USB DAC) | [1475](https://www.adafruit.com/product/1475) | 1 | 4.95 | 4.95 | audio out |
| Tactile switches 12 mm (10-pack) ✓ | [1119](https://www.adafruit.com/product/1119) | 2 pk | 2.50 | 5.00 | 13 panel buttons + spares |
| **Stereo 2.8 W Class-D amp, I2C AGC (TPA2016)** ✓ | [1712](https://www.adafruit.com/product/1712) | 1 | 9.95 | 9.95 | internal speakers (on the RP2040 I2C bus) |
| **Mono enclosed speaker 3 W 4 Ω ×2** ✓ | [3351](https://www.adafruit.com/product/3351) | 2 | 3.95 | 7.90 | stereo pair; the 1669 set stays OOS (DigiKey stocks it if preferred) |
| Switched 3.5 mm stereo jack (headphone detect) | generic panel-mount TRS w/ switch | 1 | 2 | 2.00 | headphones optional — insert mutes the amp |
| Perma-Proto half-size (singles ×3 — 3-pack OOS) ✓ | [1609](https://www.adafruit.com/product/1609) | 3 | 4.50 | 13.50 | interconnect boards |
| Hook-up wire, JST kits, headers | misc | — | — | ~15 | wiring |
| **Adafruit subtotal (cart built 2026-07-17: $61.15 + wire/misc)** | | | | **≈ 76** | |

> Adafruit doesn't stock: motorized faders, the SSD1322 OLED, the UPS, or bare
> 18650 cells — those come from the vendors below.

## 🛒 The seek mechanism (custom belt drive — see enclosure.md)

| Part | Source | Qty | ~$ |
|---|---|---|---|
| Manual long-travel slide pot, 10 kΩ linear, ~85–90 mm travel, body ≤118 mm (**VERIFY**) | DigiKey/Mouser (Bourns PTB-class) or Soundwell | 1 (+1 spare) | 4–8 |
| N20 micro gearmotor, 6 V, low ratio (≤30:1) — backdrivable | Amazon/Pololu | 2 (spare) | 8 |
| GT2 16T pulleys ×2 + GT2 belt (200 mm loop) | printer-parts vendors | 1 set | 6 |
| Slip-clutch hub | 3D-printed (design ours) | — | — |

> **No packaged motorized faders in the build anymore** — the EQ/volume/balance
> are slim manual pots and seek is the custom drive. Bench-prove the slip clutch
> with these parts before cutting the panel.

## 🛒 Slim pots (EQ ×11 + volume + balance)

| Part | Source | Qty | ~$ |
|---|---|---|---|
| Slim slide pot, 45 mm travel, 10 kΩ linear (9 mm body) | DigiKey/Mouser/Soundwell | 13 (11 EQ + vol + spare) | 20–30 |
| Mini slide pot, 20 mm travel (balance) | same | 1 | 2 |

## 🛒 Geekworm — power

| Part | Source | Qty | ~$ |
|---|---|---|---|
| X728 UPS/BMS HAT (current rev, V2.5+) | [geekworm.com](https://geekworm.com/products/x728) / [Amazon](https://www.amazon.com/dp/B087FXLZZH) | 1 | 36 |

## 🛒 Battery vendor (18650BatteryStore / Illumn)

| Part | Qty | ~$ ea | ~$ |
|---|---|---|---|
| Samsung 35E 18650 (3500 mAh, button-top per X728 holder spec) | 4 | 6 | 24 |

> Buy cells from a reputable battery house, not marketplace listings — counterfeit
> 18650s are endemic. Verify button vs flat top against the X728 holder.

## 🛒 OLED readout (pick one)

| Option | Source | ~$ | Note |
|---|---|---|---|
| Generic SSD1322 3.12″ 256×64 SPI | [Amazon](https://www.amazon.com/Display-Module-Graphic-SSD1322-Monochrome/dp/B0CHP98SVP) / [BuyDisplay ER-OLED032-1](https://www.buydisplay.com/3-2-inch-oled-display-module-ssd1322-controller-256x64-dot-green-on-black) | 22–28 | fastest/cheapest |
| Newhaven **NHD-3.12-25664UCY2** (yellow/amber) | [newhavendisplay.com](https://newhavendisplay.com/3-12-inch-yellow-graphic-oled-module/) | ~38 | premium, proper datasheet + mechanical drawing — best for the aluminum build |

> Order the **SPI** interface variant, and amber/yellow for the retro look.

## Misc (Amazon/local)

| Part | ~$ |
|---|---|
| Electrolytic caps 2200 µF/10 V ×2, inline fuse + holder, rocker/slide power switch | 8 |
| M2.5/M3 machine screws, standoffs, heat-set inserts (for the printed case) | 10 |
| **Aluminum knobs** (final build): 11× fader caps + 2× knurled encoder knobs — 3D-printed on the prototype | 25–40 |
| **Kickstand hardware**: 2× adjustable-torque (position-control) hinges, rubber bumper feet ×6, 2× ø8 magnets + steel discs | 20 |

## Totals

| | ~$ |
|---|---|
| Adafruit (incl. amp + speakers) | 98 |
| Seek mechanism (pot + N20 + GT2) | 20 |
| Slim pots (EQ + vol + bal) | 25–35 |
| Power (Geekworm + cells) | 60 |
| OLED | 22–38 |
| Misc | 18 |
| **New parts total** | **≈ 245–270** |

(On top of the already-owned Pi/HyperPixel/SD ≈ $110 — consistent with the
[BOM](BOM.md) estimate of $490–540 all-in.)

## Suggested order of orders

1. **Adafruit cart + the seek-mechanism kit** (long-travel pot, N20, GT2 set) →
   bench-prove the belt drive + slip clutch (issue #65) before cutting the panel.
2. **Slim pots + OLED** → the full control surface.
3. **X728 + cells** → battery/power milestone (Phase 7).

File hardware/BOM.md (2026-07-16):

# Bill of Materials

Prices are rough USD, mid-2020s, single-unit hobby quantities. This is a
**buildable** BOM for the full build you chose: motorized graphic EQ + motorized
volume + motorized seek, single integrated body.

> 🛒 **Ready to order?** [PARTS.md](PARTS.md) is the vendor shopping list (real
> SKUs, Adafruit-first). Datasheets: [datasheets/](datasheets/). Case rules +
> dimension findings: [enclosure.md](enclosure.md).

> ⚠️ **Read the fader note first — it's the biggest cost and space driver.**

## Compute & display

| Part | Notes | ~$ |
|---|---|---|
| **Raspberry Pi 4 Model B (2–4 GB)** | The build target. Ample for Pygame + ALSA EQ + FFT, has a 3.5 mm jack, and is easier on the battery than a Pi 5. | 45 |
| microSD 32 GB (A1) | OS + app | 8 |
| RP2040 (Raspberry Pi Pico) | Real-time controls + motor PID + the OLED readout. Cheap, 26 GPIO, PIO, 3 ADC. | 4 |
| **Pimoroni HyperPixel 4.0 Square** (720×720, DPI, touch) | The center screen — a small square LCD showing a multi-view UI (now playing / playlists / queue). ⚠️ DPI uses **all 40 GPIO** — see notes below. | 55 |
| **Amber OLED readout strip** (SSD1322, 256×64, SPI) | The retro top readout: elapsed time, scrolling title, mini-spectrum. Driven by the **RP2040** (`DISP` serial commands), not the Pi. | 25 |
| **USB DAC** (e.g. Sabrent/generic) | Audio out. A GPIO I2S HAT can't be used (HyperPixel's DPI takes the I2S pins). Pi 3.5 mm jack works for early testing. | 15 |
| **TPA2016 stereo 2.8 W Class-D amp** | Internal speakers. I2C gain/AGC/mute — rides the **RP2040 expander bus** (5th device). | 10 |
| **Enclosed stereo speakers, 3 W 4 Ω** (70×30×17 mm ea.) | Sealed backs = no custom acoustic chamber. Standalone playback, no headphones needed. | 8 |
| **Switched 3.5 mm headphone jack** | Insert detection (→ MCP23017 spare input) mutes the amp — headphones optional. | 2 |

> **HyperPixel I/O note:** the HyperPixel's DPI interface consumes all 40 GPIO
> pins (incl. standard I2C and I2S). That's fine here because everything else is on
> **USB**: controls/pots/faders **and battery sensing** run on the **RP2040** (USB
> serial), **audio** goes to a **USB DAC**, and the **UPS powers the Pi via USB-C**
> rather than stacking on the header. An alternate I2C is broken out on BCM 10/11 if
> ever needed. This is exactly why the two-brain (Pi + RP2040) split pays off.

## The motorized faders (the expensive part)

Full build = **10 motorized faders**: 7 EQ + 1 preamp + 1 volume + 1 seek.

| Part | Qty | Notes | ~$ ea | ~$ |
|---|---|---|---|---|
| ALPS RSA0N11M9 **60 mm motorized** fader | 10 | 100 mm won't fit a 5″ body — use 60 mm. Each has a motor + a wiper pot for position feedback + a touch-sense pin. | 18 | 180 |
| DRV8833 dual H-bridge motor driver | 5 | One drives two fader motors. | 2 | 10 |
| CD74HC4067 16-ch analog mux | 1–2 | The Pico has only 3 ADC channels; mux the 10 fader wipers + balance pot through one ADC. | 1.5 | 3 |
| **PCA9685 16-ch PWM driver** | 2 | ⚠️ **Required** — 10 motors need 20 PWM lines; the Pico doesn't have them. Drives the DRV8833 inputs over I2C. Caveat: ~1.5 kHz max PWM = brief audible buzz *while a fader moves* (moves are short; the reduced build avoids this entirely). | 5 | 10 |
| **MPR121 12-ch capacitive touch** | 1 | All 10 fader touch-sense lines over I2C (the ALPS conductive-knob pin is exactly what this reads). | 8 | 8 |
| **MCP23017 16-ch GPIO expander** | 1 | All 13 panel buttons over the same I2C bus — keeps the Pico's pin budget closing. | 2 | 2 |

> **Why the expanders:** direct-wiring everything needs ~55 signals; the Pico has
> 26 GPIO. With PCA9685 (motor PWM) + MPR121 (touch) + MCP23017 (buttons) sharing
> one 2-pin I2C bus, the budget closes with room for the OLED. Full pin map in
> [wiring.md](wiring.md).

**Why 7-band EQ, not 10:** eleven fader bodies (18.5 mm wide each, per the ALPS
datasheet) would need ~220 mm of width. Seven EQ + preamp (8 in the bank) need
~155 mm — which sets the body width at **~165 mm** (the original 127 mm/5″ target
can't hold a motorized bank; options in [enclosure.md](enclosure.md)). Volume +
seek mount horizontally. See [wiring.md](wiring.md).

**Want to cut cost/scope?** Make only **volume + seek** motorized (2 faders) and
use plain (non-motorized) slide pots for EQ. Saves ~$140 and most of the motor
drivers/PID work. The firmware already separates "motorized" from "read-only"
faders, so this is a config change, not a rewrite.

## Buttons, knobs, encoders

| Part | Qty | Notes | ~$ |
|---|---|---|---|
| Momentary tactile buttons (12 mm) | 13 | 5 transport + shuffle + repeat + eq-on + **eq-preset** + **3 view-switch** + eject/spare (ButtonId 0–12, read via the MCP23017) | 7 |
| Rotary encoder w/ push (EC11) | 2 | playlist scroll + select; menu | 4 |
| **Balance slide pot (non-motorized, 45 mm)** | 1 | The L/R slider from the concept — read via the mux as `POT 0`. | 2 |
| Addressable LED (WS2812) strip/segment | 1 | VU / status glow | 3 |

## Power (handheld) — see [power.md](power.md) for the full design

| Part | Notes | ~$ |
|---|---|---|
| UPS/BMS HAT for Pi (Geekworm X728 or Waveshare UPS HAT B) | 5 V/5 A out, 18650 holders, I2C battery monitoring + safe shutdown. | 30 |
| 18650 Li-ion cells ×4 (3500 mAh, e.g. Samsung 35E) | ~50 Wh ≈ 6 h runtime. Use 2 for ~3 h, 6 for ~9 h. | 40 |
| Bulk caps (1000–2200 µF) + fuse + power switch | Absorb motor-slew spikes at the driver rail. | 5 |

## Body & misc

| Part | Notes | ~$ |
|---|---|---|
| Enclosure (book form, working envelope ~165×210×32 mm — see [enclosure.md](enclosure.md)) | FDM prototype (PETG/ABS), CNC anodized aluminum final. | 15+ |
| Fader knob caps, standoffs, JST wiring, protoboard/PCB | | 20 |

## Rough total

| Group | ~$ |
|---|---|
| Compute & display & audio (incl. OLED, amp, speakers) | 172 |
| Motorized faders + drivers + mux + I2C expanders | 213 |
| Buttons/knobs/LEDs | 16 |
| Power (UPS + 4×18650, see [power.md](power.md)) | 75 |
| Body & misc | 35 |
| **Total (full motorized build)** | **≈ 510–560** |
| *Reduced (only volume+seek motorized, plain EQ pots)* | *≈ 360–390* |

## Sourcing notes

- Motorized faders: Mouser/Digikey for genuine ALPS; budget clones exist on
  AliExpress but wiper quality/backlash varies — buy one and test before ten.
- Confirm the fader's touch-sense wiring; some variants need a capacitive
  touch IC, others expose a conductive-knob pin.
- HyperPixel: verify the `vc4-kms-dpi-hyperpixel4sq` overlay + touch on your OS
  version before committing to the enclosure cutout (see docs/pi-bringup.md).
- SSD1322 OLED strips ship in SPI/parallel variants — order the **SPI** one.

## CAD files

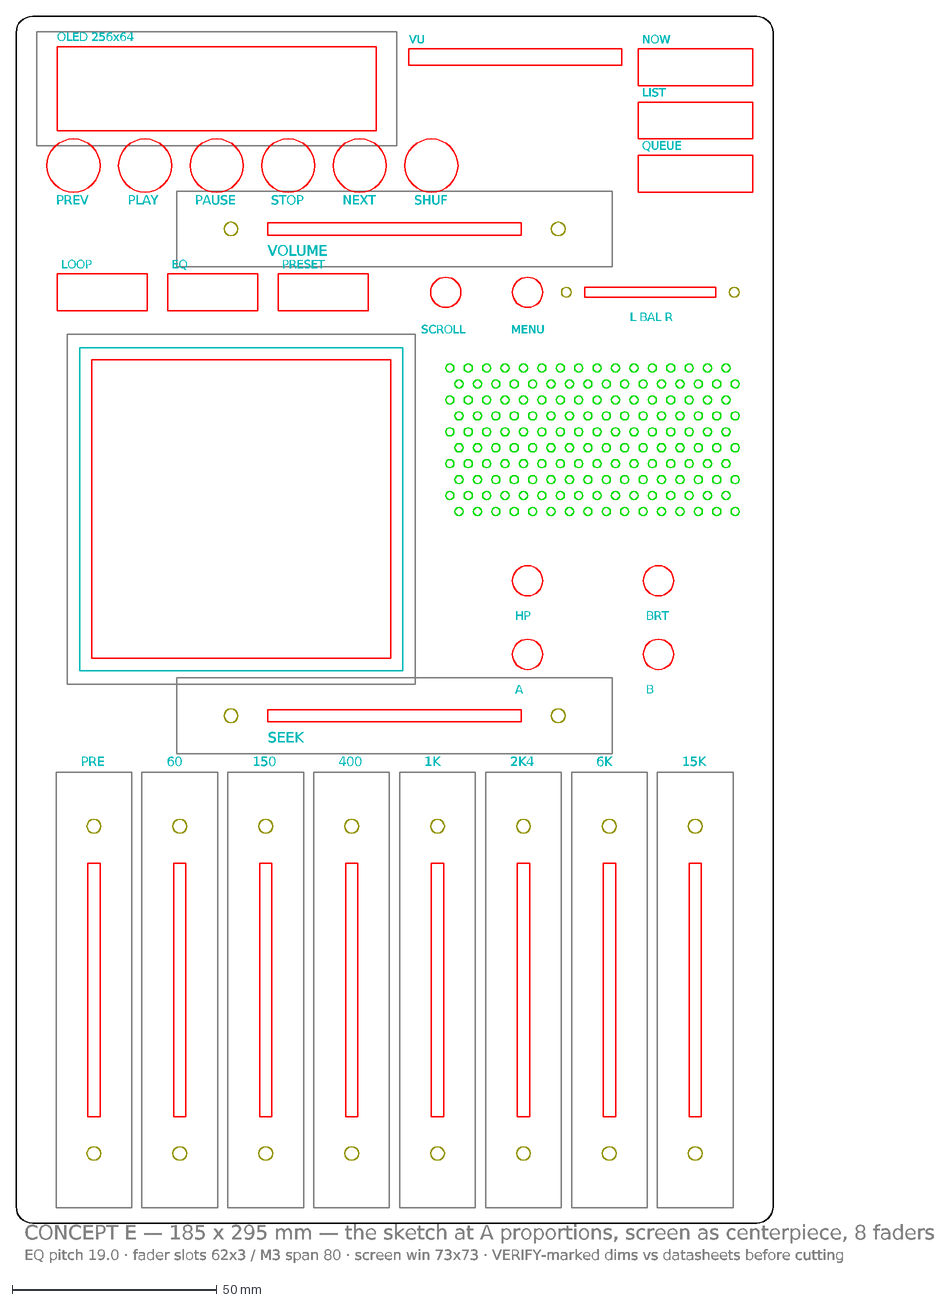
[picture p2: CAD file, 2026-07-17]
hardware/cad/concepts/concept-e.dxf
OLED 256x64
NOW
LIST
QUEUE
VU
PREV
PLAY
PAUSE
STOP
NEXT
SHUF
VOLUME
LOOP
EQ
PRESET
SCROLL
MENU
L BAL R
HP
BRT
A
B
SEEK
PRE
60
150
400
1K
2K4
6K
15K
CONCEPT E — 185 x 295 mm — the sketch at A proportions, screen as centerpiece, 8 faders
EQ pitch 19.0 · fader slots 62x3 / M3 span 80 · screen win 73x73 · VERIFY-marked dims vs datasheets before cutting

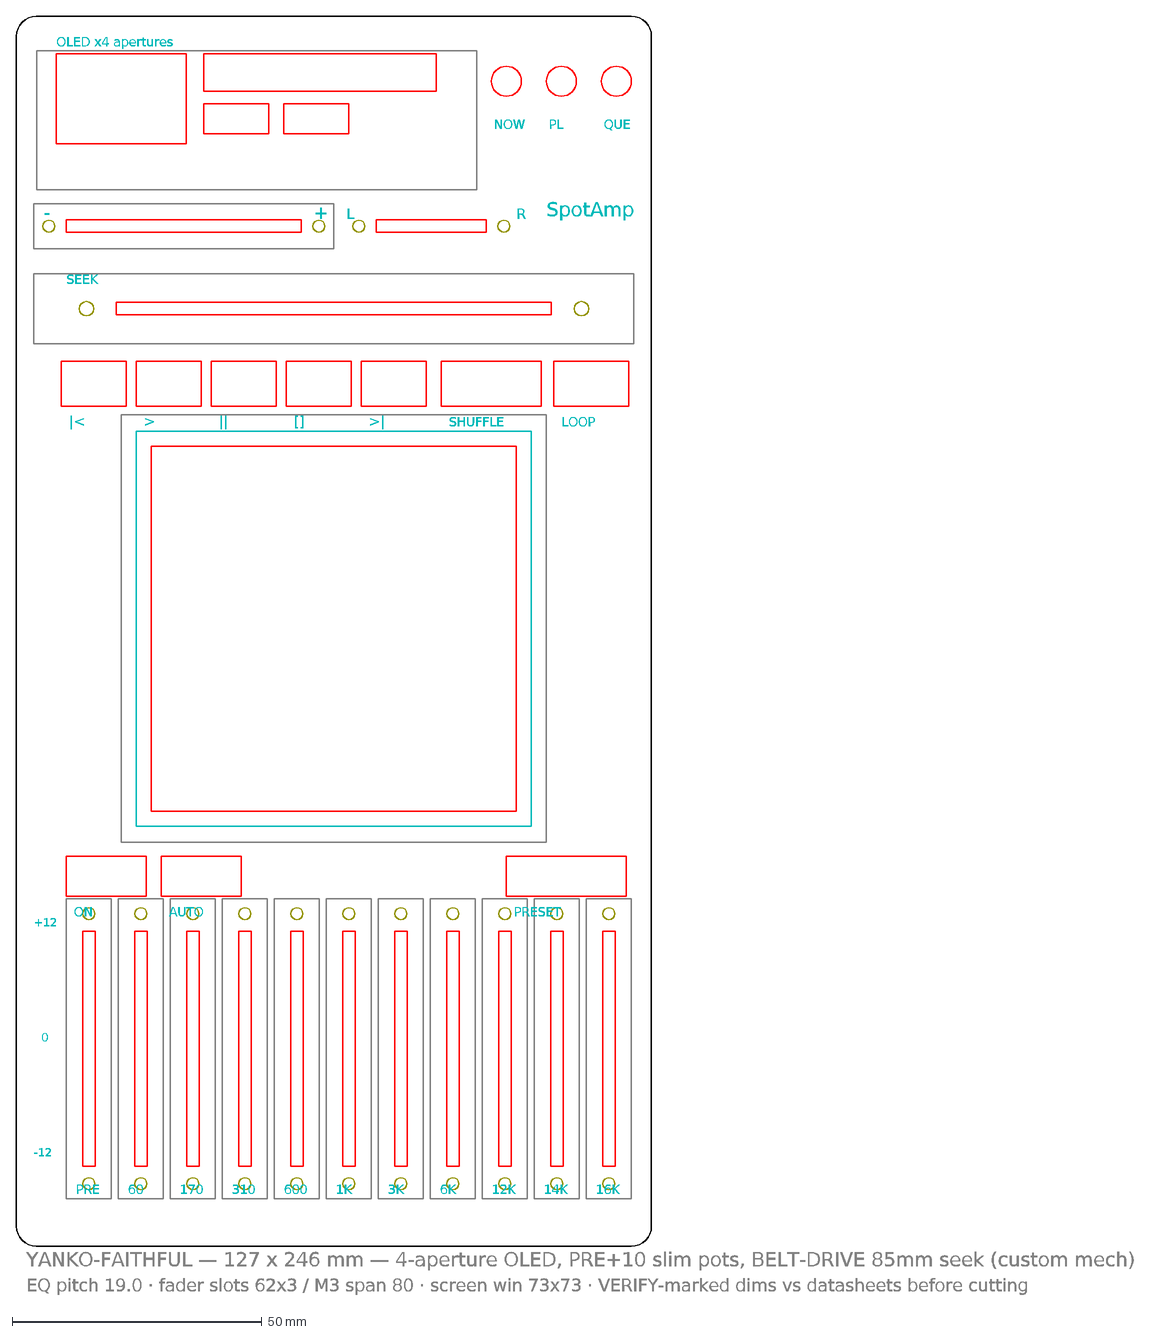
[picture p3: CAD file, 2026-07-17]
hardware/cad/front-panel-final.dxf
OLED x4 apertures
NOW
PL
QUE
-
+
L
R
SpotAmp
SEEK
|<
>
||
[]
>|
SHUFFLE
LOOP
ON
AUTO
PRESET
+12
0
-12
PRE
60
170
310
600
1K
3K
6K
12K
14K
16K
YANKO-FAITHFUL — 127 x 246 mm — 4-aperture OLED, PRE+10 slim pots, BELT-DRIVE 85mm seek (custom mech)
EQ pitch 19.0 · fader slots 62x3 / M3 span 80 · screen win 73x73 · VERIFY-marked dims vs datasheets before cutting

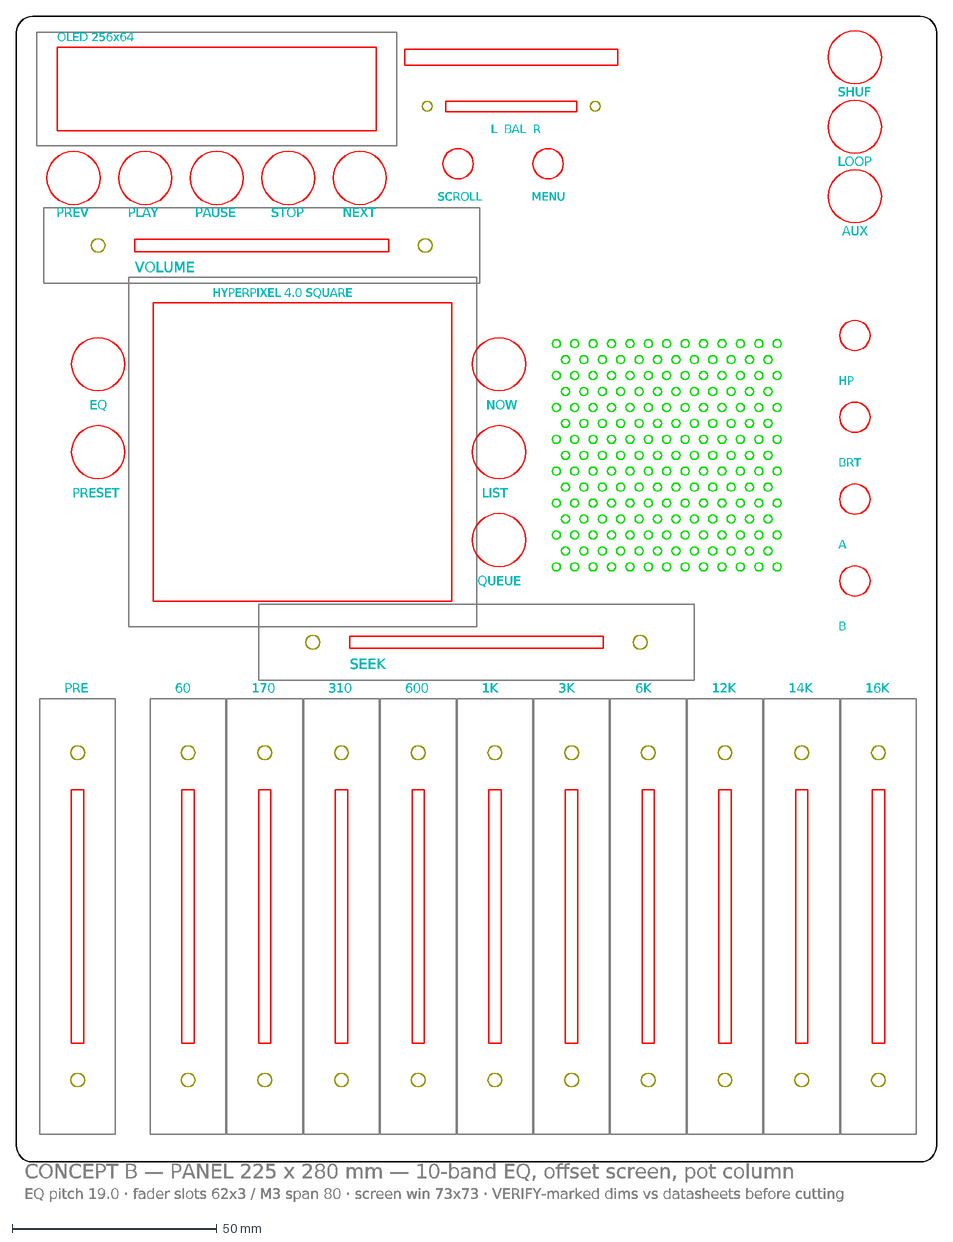
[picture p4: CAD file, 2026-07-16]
hardware/cad/concepts/concept-b.dxf
OLED 256x64
L BAL R
SCROLL
MENU
SHUF
LOOP
AUX
PREV
PLAY
PAUSE
STOP
NEXT
VOLUME
HYPERPIXEL 4.0 SQUARE
NOW
LIST
QUEUE
EQ
PRESET
HP
BRT
A
B
SEEK
PRE
60
170
310
600
1K
3K
6K
12K
14K
16K
CONCEPT B — PANEL 225 x 280 mm — 10-band EQ, offset screen, pot column
EQ pitch 19.0 · fader slots 62x3 / M3 span 80 · screen win 73x73 · VERIFY-marked dims vs datasheets before cutting

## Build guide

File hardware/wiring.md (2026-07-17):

# Wiring & physical layout

## Schematics

| Diagram | What it shows |
|---|---|
| [**System wiring**](diagrams/system-wiring.svg) | Full power + data topology: battery → UPS → Pi/motor rail; USB to the RP2040 + DAC; the I2C expander bus (PCA9685/MPR121/MCP23017) out to the faders |
| [**Pico pinout**](diagrams/pico-pinout.svg) | Every RP2040 pin assignment (19 of 26 used, spares marked) |
| [**Front panel (authoritative)**](cad/) | The dimensioned cut drawing — `cad/front-panel.dxf` / `.svg` |

System wiring

Pico pinout

Front panel

> ⚠️ **Dimension findings** (ALPS datasheet + the dimensioned cut drawing):
> fader bodies are **18.5 mm wide × 26 mm deep × 106.5 mm long (M3 span 80 mm)**.
> The 8-fader bank therefore needs ~155 mm of width and **~110 mm of height** —
> honest envelope: **175 × 280 × 32 mm (6.9″ × 11″ × 1.25″)**, proven with real
> clearances in **[cad/front-panel.dxf](cad/)** (the authoritative drawing).
> Full analysis + the compact fallback: [enclosure.md](enclosure.md).

## Front-panel layout (ASCII summary — superseded by cad/, kept for orientation)

Mirrors the software's regions so the code and the hardware agree:

```
┌───────────────────────────────────────────┐  ← ~127 mm wide
│  SPOTAMP       (title)   │
├───────────────────────────────────────────┤
│  0:42   [ amber OLED readout ]   320 kbps  │   PHYSICAL panel
│  ░░▓▓██▓░ title + spectrum       44 kHz    │   SSD1322 256×64 SPI OLED on the
│  |◀ ▶ ▮▮ ■ ▶| SHUF LOOP PRESET [==BAL==]   │   RP2040 (`DISP` commands) +
│  [====VOL (motorized)====]                 │   buttons + balance pot + volume
├───────────────────────────────────────────┤
│  [NP] [PL] [Q]  (view-switch buttons)     │   PHYSICAL (ButtonId 9–11)
│   ┌─────────────────────────────┐         │
│   │                             │         │   SCREEN
│   │   HyperPixel 4.0 Square     │         │   720×720 DPI touchscreen
│   │   (multi-view UI: now       │         │   ⚠ occupies ALL 40 GPIO —
│   │   playing/playlists/queue)  │         │   controls/battery on RP2040,
│   └─────────────────────────────┘         │   audio via USB DAC
│                                           │
├───────────────────────────────────────────┤
│  EQ:  ▮ ▮ ▮ ▮ ▮ ▮ ▮   ▮(pre)              │   PHYSICAL panel
│      60 150 400 1k 2k4 6k 15k              │   8 motorized 60 mm faders
├───────────────────────────────────────────┤
│  [====VOL====]      [====SEEK====]         │   2 motorized faders (horizontal)
└───────────────────────────────────────────┘
```

## Pico (RP2040) pin plan — expander architecture

**Direct-wiring does not fit**: 10 motors × 2 PWM + 10 touch + 13 buttons +
mux + encoders ≈ **55 signals vs the Pico's 26 GPIO**. Everything high-count
rides one I2C bus instead:

```
                        ┌── PCA9685 #1 ──▶ DRV8833 ×3 ──▶ fader motors 0–5
                        ├── PCA9685 #2 ──▶ DRV8833 ×2 ──▶ fader motors 6–9
Pico I2C (2 pins) ──────┼── MPR121  ──▶ 10 fader touch-sense lines
                        ├── MCP23017 ──▶ 13 panel buttons + headphone-jack detect
                        └── TPA2016 amp ──▶ internal stereo speakers (gain/AGC/mute)
```

| Function | Pico pins | Count |
|---|---|---|
| I2C bus (PCA9685 ×2, MPR121, MCP23017, TPA2016) | GP4/GP5 | 2 |
| Mux (CD74HC4067) select S0–S3 | GP6–GP9 | 4 |
| Mux common out → ADC (wipers + balance pot) | GP26 (ADC0) | 1 |
| OLED readout (SSD1322, SPI + DC/CS/RST) | GP10–GP14 | 5 |
| Encoders (EC11) ×2 + push | GP16–GP21 | 6 |
| WS2812 LEDs | GP22 (PIO) | 1 |
| USB | to Pi (CDC serial + power) | — |
| **Total** | | **19 of 26** ✅ |

Each motorized fader needs **three** connections handled together:
1. **Motor** → a DRV8833 channel, its two inputs driven by PCA9685 outputs.
2. **Wiper** → a mux input → ADC, for the PID's position feedback.
3. **Touch** → an MPR121 electrode, so the Pi knows to stop driving it.

> **PWM-frequency caveat:** the PCA9685 tops out at ~1.5 kHz, which is audible as
> a faint buzz *while a fader is moving*. Moves last well under a second, and the
> **reduced build** (only volume + seek motorized, driven directly from Pico PWM
> pins at 20 kHz+) sidesteps it completely.

## Electrical detail notes (desk-verified against datasheets, 2026-07-16)

**I2C address map** — no conflicts ✓:

| Device | Addr | Note |
|---|---|---|
| PCA9685 #1 | 0x40 | default |
| PCA9685 #2 | 0x41 | solder jumper A0 |
| MCP23017 | 0x20 | A0–A2 → GND |
| X728 fuel gauge (MAX17040) | 0x36 | see battery note below |
| TPA2016 amp | 0x58 | fixed |
| MPR121 | 0x5A | ADDR → GND |

- **Pull-ups**: every breakout ships its own (typ. 10 k). Six in parallel ≈ 1.7 k —
  near the 3 mA sink limit. If the bus misbehaves, desolder pull-ups from all but
  one board.
- **Motor-safe boot**: PCA9685 outputs are indeterminate until configured — tie
  both boards' **/OE to GP3 with a pull-up** so motors stay disabled until the
  firmware releases them. (GP3 was spare.)
- **Simultaneous-slew current**: stagger the PCA9685 per-channel ON offsets so 10
  motors don't switch in phase; with the 2× 2200 µF bulk caps that tames rail sag.
- **Touch-sense wiring**: each fader's T terminal → an MPR121 electrode. Keep the
  runs short and away from the motor leads (they're capacitive sense lines).

**Mux channel map** (CD74HC4067 → ADC0):

| CH | Signal |
|---|---|
| 0–6 | EQ band wipers 0–6 |
| 7 | preamp wiper |
| 8 | volume wiper |
| 9 | seek wiper |
| 10 | balance pot |
| 11–15 | spare |

**Battery telemetry** — the X728 can't stack on the Pi (HyperPixel owns the
header); it runs beside it and powers the Pi over USB-C. Its **MAX17040 fuel
gauge is I2C** — so jumper the X728 header's SDA/SCL/GND over to the **RP2040
bus** (addr 0x36, no conflict) and the firmware reports real state-of-charge over
serial (`power.py` already knows the MAX17040 registers). X728's AC-loss/PLD
signal → **GP2** (was spare) for charge-state. Fallback if the jumpering fights
us: a resistor divider off the battery to **GP28/ADC2** (for a 1S pack, 4.2 V max:
39 k / 100 k → 3.0 V full-scale — **verify the X728's cell topology first**).

## Control loop (firmware)

Per motorized fader, ~1 kHz:

```
error = target - read_position(fader)
if touched(fader):        # user wins
    motor_off(fader); report EV FADER when it settles
else:
    drive = PID(error)    # tune Kp/Ki/Kd per fader
    motor_pwm(fader, clamp(drive))
```

See `firmware/src/main.cpp` for the skeleton.

## Power & audio

- LiPo → power board (5 V boost) → Pi 4; motors get their own regulated rail off
  the same pack (H-bridges draw spikes — decouple well, keep motor ground and
  logic ground joined at one star point).
- **USB DAC** on a Pi USB port (the HyperPixel's DPI takes the I2S pins, so no
  GPIO DAC) → line out → **switched headphone jack** → **TPA2016 stereo amp** →
  internal enclosed speakers. Headphone insertion is sensed (MCP23017 input) and
  firmware mutes the amp over I2C. Pi USB budget: RP2040 + DAC = 2 of 4 ports.
- External outputs are **software**: Spotify Connect transfer for Sonos/Connect
  gear (Web API `transfer_to`), and BT A2DP via the Pi 4's onboard Bluetooth.

## Enclosure

- Book form, ~200 × 127 × 25 mm. Faders and their travel set the depth — 60 mm
  faders + motor bodies are the tallest components; plan ~20 mm behind the panel.
- Print the front panel with slots for fader travel and cutouts for the LCD,
  buttons, and encoders. A kickstand echoes the Yanko concept's EQ-base stand.
- CAD lives here later (`hardware/cad/`), source + STL.

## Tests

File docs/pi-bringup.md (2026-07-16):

# Raspberry Pi bring-up (standalone player)

The exact, reproducible steps to turn a fresh Pi 4 B into the standalone player:
go-librespot for audio + the WinAmp app on the screen. Written from a real
bring-up on 2026-07-15 (Raspberry Pi OS Bookworm, 64-bit).

## 1. Flash + first boot

- **Raspberry Pi OS (64-bit), Desktop**, via Raspberry Pi Imager.
- In the Imager gear: set hostname (`winamp`), **enable SSH**, username, Wi-Fi, locale.
- First boot:
  ```bash
  sudo apt update && sudo apt full-upgrade -y
  sudo raspi-config   # Interface: enable I2C, SPI, Serial
  sudo reboot
  ```

## 2. go-librespot (the audio engine)

```bash
sudo apt-get install -y libogg-dev libvorbis-dev libflac-dev libasound2-dev curl
mkdir -p ~/go-librespot && cd ~/go-librespot
URL=$(curl -s https://api.github.com/repos/devgianlu/go-librespot/releases/latest \
      | grep -o 'https://[^"]*linux_arm64[^"]*\.tar\.gz' | head -1)
curl -L "$URL" -o go-librespot.tar.gz && tar xzf go-librespot.tar.gz && chmod +x go-librespot
```

Config `~/.config/go-librespot/config.yml` (see [../config/go-librespot.example.yaml](../config/go-librespot.example.yaml)):
```yaml
device_name: "Winamp Physical Edition"
device_type: computer
audio_backend: alsa
audio_device: plughw:CARD=Headphones   # Pi 3.5mm jack; USB DAC on the real build
credentials:
  type: interactive
server:
  enabled: true
  address: localhost
  port: 3678
```

### Headless OAuth (no browser on the Pi)

1. `cd ~/go-librespot && ./go-librespot` — prints an `accounts.spotify.com/authorize?...` URL.
2. Open that URL in a browser **on another machine**, authorize.
3. It redirects to `http://127.0.0.1:<PORT>/login?code=…` which won't load — **copy that URL**.
4. In a second SSH session on the Pi: `curl "http://127.0.0.1:<PORT>/login?code=…"`.
5. go-librespot logs in and caches `credentials.json` — standalone from now on.

### Audio device

`aplay -l` lists the cards; the 3.5mm jack is `bcm2835 Headphones` (card 2 here), so
`audio_device: plughw:CARD=Headphones`. `raspi-config`'s audio default does **not**
affect go-librespot's ALSA path — set the device explicitly. If silent, `alsamixer`
(F6 → the card → unmute `M`, raise volume). *The final build uses a USB DAC (issue #12).*

### Run as a service (auto-start on boot)

Install [../deploy/go-librespot.service](../deploy/go-librespot.service):
```bash
sudo cp ~/WinAmpPlayer/deploy/go-librespot.service /etc/systemd/system/
sudo systemctl daemon-reload && sudo systemctl enable --now go-librespot
journalctl -u go-librespot -f
```

**Standalone check:** `curl -X POST http://localhost:3678/player/play -H 'Content-Type: application/json' -d '{"uri":"spotify:playlist:37i9dQZF1DXcBWIGoYBM5M"}'` — music plays with no phone/Spotify app open.

## 3. The WinAmp app

```bash
cd ~ && git clone https://github.com/Paco5687/WinAmpPlayer.git
cd WinAmpPlayer/pi
python3 -m venv venv && source venv/bin/activate
pip install -r requirements.txt          # piwheels provides arm64 pygame
cp config.example.toml config.toml       # set backend="librespot", controls="mock"
SDL_VIDEODRIVER=dummy python -c "import winamp_player.app; print('ok')"   # sanity
```

### Run on the display (labwc / Wayland)

The Pygame app needs the Pi's Wayland session (not SSH). Launch it onto the session:
```bash
export XDG_RUNTIME_DIR=/run/user/1000 DBUS_SESSION_BUS_ADDRESS=unix:path=/run/user/1000/bus
systemd-run --user --unit=winamp-ui \
  --setenv=WAYLAND_DISPLAY=wayland-0 --setenv=SDL_VIDEODRIVER=wayland \
  --working-directory=$HOME/WinAmpPlayer/pi \
  $HOME/WinAmpPlayer/pi/venv/bin/python -m winamp_player
```
## 4. HyperPixel 4.0 Square + kiosk autostart

The real display is a **Pimoroni HyperPixel 4.0 Square (720×720, DPI)**. DPI uses
all 40 GPIO, so disable the GPIO interfaces first, then add the overlay:

```bash
sudo raspi-config nonint do_i2c 1   # DPI needs the I2C/SPI GPIO
sudo raspi-config nonint do_spi 1
echo "dtoverlay=vc4-kms-dpi-hyperpixel4sq" | sudo tee -a /boot/firmware/config.txt
sudo reboot
```

After reboot the panel is output `DPI-1` at 720×720. **Don't** rotate with the
overlay's `rotate=` — that flips the display at the KMS level but *not the touch
matrix*. Rotate at the **compositor** level instead (moves display + touch
together) — the kiosk launcher does this with `wlr-randr --output DPI-1
--transform 180`.

### Kiosk autostart (boots straight into the UI)

Use the files in [`../deploy/`](../deploy/):

```bash
mkdir -p ~/.config/systemd/user
cp ~/WinAmpPlayer/deploy/winamp-kiosk.service ~/.config/systemd/user/
cp ~/WinAmpPlayer/deploy/winamp-kiosk.sh ~/.config/winamp-kiosk.sh
chmod +x ~/.config/winamp-kiosk.sh
sudo loginctl enable-linger "$USER"       # user manager starts at boot
systemctl --user daemon-reload
systemctl --user enable --now winamp-kiosk.service
```

Set `fullscreen = true` in `config.toml` (fills the 720×720 panel and hides the
cursor). The launcher waits for the Wayland socket, so it's robust to boot timing;
`Restart=on-failure` keeps it up, while a clean `q`/Esc still exits.

> RPi's labwc runs the *system* autostart and ignores `~/.config/labwc/autostart`;
> the XDG `.desktop` route was flaky on boot too. A **systemd user service** is the
> reliable path here.

## 5. Remote control from a laptop (optional, dev)

Add the laptop's SSH public key to the Pi's `~/.ssh/authorized_keys` for passwordless
`ssh bkern@winamp.local` — handy for deploying/logging without a keyboard on the Pi.

> ⚠️ Gotcha: don't `pkill -f "python -m winamp_player"` over SSH — the pattern matches
> the SSH command's own command line and kills your session. Use
> `systemctl --user stop winamp-ui` instead.

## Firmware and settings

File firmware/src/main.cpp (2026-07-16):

// WinAmp Physical Edition — RP2040 controls firmware.
//
// Implements the full serial protocol (docs/serial-protocol.md) over USB CDC:
//   in : FADER, FADER_RELEASE, LED, DISP TITLE/TIME/INFO, PING
//   out: EV BTN/FADER/TOUCH/ENC/POT/BAT/CHG/JACK, PONG, LOG
//
// I/O architecture (hardware/wiring.md): motors via 2x PCA9685 -> DRV8833,
// touch via MPR121, buttons via MCP23017, amp via TPA2016, battery via the
// X728's MAX17040 — all on one I2C bus. OLED readout on software SPI.
// Written desk-first (2026-07-16): compiles clean; PID gains + stiction floor
// need bench tuning with real faders.

#include <Arduino.h>
#include <Wire.h>

#include "config.h"

#if HAS_PCA9685
#include <Adafruit_PWMServoDriver.h>
#endif
#if HAS_MPR121
#include <Adafruit_MPR121.h>
#endif
#if HAS_MCP23017
#include <Adafruit_MCP23X17.h>
#endif
#if HAS_TPA2016
#include <Adafruit_TPA2016.h>
#endif
#if HAS_NEOPIXEL
#include <Adafruit_NeoPixel.h>
#endif
#if HAS_OLED
#include <U8g2lib.h>
#endif

// --------------------------------------------------------------------------- //
// devices (presence-flagged so a missing board degrades, never hangs)
// --------------------------------------------------------------------------- //
#if HAS_PCA9685
Adafruit_PWMServoDriver pcaA(ADDR_PCA_A);
Adafruit_PWMServoDriver pcaB(ADDR_PCA_B);
bool havePcaA = false, havePcaB = false;
#endif
#if HAS_MPR121
Adafruit_MPR121 touch;
bool haveTouch = false;
#endif
#if HAS_MCP23017
Adafruit_MCP23X17 mcp;
bool haveMcp = false;
#endif
#if HAS_TPA2016
Adafruit_TPA2016 amp;
bool haveAmp = false;
#endif
#if HAS_NEOPIXEL
Adafruit_NeoPixel pixels(NUM_PIXELS, PIN_NEOPIXEL, NEO_GRB + NEO_KHZ800);
#endif
#if HAS_OLED
U8G2_SSD1322_NHD_256X64_F_4W_SW_SPI oled(U8G2_R0, PIN_OLED_SCK, PIN_OLED_MOSI,
                                         PIN_OLED_CS, PIN_OLED_DC, PIN_OLED_RST);
bool haveOled = false;
#endif

// --------------------------------------------------------------------------- //
// state
// --------------------------------------------------------------------------- //
struct Fader {
  int16_t  target = -1;        // -1 = released (user owns it)
  float    pos = 0;            // filtered position, 0..1023
  float    prevErr = 0;
  bool     touched = false;
  uint16_t lastReported = 0xFFFF;
};
Fader faders[NUM_FADERS];

uint16_t balanceLast = 0xFFFF;
uint16_t buttonsLast = 0xFFFF;   // MCP GPIOAB snapshot (pull-ups: 1 = released)
uint32_t buttonsChangedAt[16] = {0};
bool     jackLast = false;

int8_t  encAccum[2] = {0, 0};
uint8_t encPrev[2] = {0, 0};
bool    encSwLast[2] = {true, true};

char  dispTitle[96] = "WINAMP · PHYSICAL EDITION";
uint32_t dispPosMs = 0, dispDurMs = 0;
uint16_t dispKbps = 0, dispKhz = 0;
uint32_t dispPosStamp = 0;       // millis() when dispPosMs was set
int16_t  marqueeX = 0;

// --------------------------------------------------------------------------- //
// serial protocol
// --------------------------------------------------------------------------- //
static void emit(const char* type, int id, long value) {
  Serial.print("EV "); Serial.print(type); Serial.print(' ');
  Serial.print(id); Serial.print(' '); Serial.println(value);
}
static void logmsg(const char* msg) { Serial.print("LOG "); Serial.println(msg); }

static char rxBuf[160];
static uint8_t rxLen = 0;

static void handleDisp(char* args) {
  char* what = strtok(args, " ");
  if (!what) return;
  if (!strcmp(what, "TITLE")) {
    char* rest = strtok(nullptr, "");            // remainder incl. spaces
    strncpy(dispTitle, rest ? rest : "-", sizeof(dispTitle) - 1);
    dispTitle[sizeof(dispTitle) - 1] = 0;
    marqueeX = 0;
  } else if (!strcmp(what, "TIME")) {
    dispPosMs = strtoul(strtok(nullptr, " ") ?: "0", nullptr, 10);
    dispDurMs = strtoul(strtok(nullptr, " ") ?: "0", nullptr, 10);
    dispPosStamp = millis();
  } else if (!strcmp(what, "INFO")) {
    dispKbps = atoi(strtok(nullptr, " ") ?: "0");
    dispKhz  = atoi(strtok(nullptr, " ") ?: "0");
  }
}

static void handleCommand(char* line) {
  char* verb = strtok(line, " ");
  if (!verb) return;
  if (!strcmp(verb, "PING")) {
    Serial.println("PONG");
  } else if (!strcmp(verb, "FADER")) {
    int id = atoi(strtok(nullptr, " ") ?: "-1");
    int pos = atoi(strtok(nullptr, " ") ?: "0");
    if (id >= 0 && id < NUM_FADERS)
      faders[id].target = constrain(pos, 0, (int)FADER_MAX);
  } else if (!strcmp(verb, "FADER_RELEASE")) {
    int id = atoi(strtok(nullptr, " ") ?: "-1");
    if (id >= 0 && id < NUM_FADERS) faders[id].target = -1;
  } else if (!strcmp(verb, "LED")) {
#if HAS_NEOPIXEL
    int i = atoi(strtok(nullptr, " ") ?: "0");
    int r = atoi(strtok(nullptr, " ") ?: "0");
    int g = atoi(strtok(nullptr, " ") ?: "0");
    int b = atoi(strtok(nullptr, " ") ?: "0");
    if (i >= 0 && i < (int)NUM_PIXELS) {
      pixels.setPixelColor(i, pixels.Color(r, g, b));
      pixels.show();
    }
#endif
  } else if (!strcmp(verb, "DISP")) {
    handleDisp(strtok(nullptr, ""));
  }
}

static void pollSerial() {
  while (Serial.available()) {
    char c = (char)Serial.read();
    if (c == '\n' || c == '\r') {
      if (rxLen) { rxBuf[rxLen] = 0; handleCommand(rxBuf); rxLen = 0; }
    } else if (rxLen < sizeof(rxBuf) - 1) {
      rxBuf[rxLen++] = c;
    } else {
      rxLen = 0;  // overlong line: drop it
    }
  }
}

// --------------------------------------------------------------------------- //
// analog mux
// --------------------------------------------------------------------------- //
static uint16_t readMux(uint8_t channel) {
  for (uint8_t i = 0; i < 4; i++) digitalWrite(PIN_MUX_S[i], (channel >> i) & 1);
  delayMicroseconds(8);                 // mux + RC settle
  return analogRead(PIN_MUX_ADC);       // 10-bit, 0..1023
}

// --------------------------------------------------------------------------- //
// motors (PCA9685 -> DRV8833). Fader f uses channels f*2 / f*2+1.
// --------------------------------------------------------------------------- //
static void motorRaw(uint8_t f, uint16_t in1, uint16_t in2) {
#if HAS_PCA9685
  uint8_t chan = (f * 2) % 16;
  Adafruit_PWMServoDriver* p = (f < 8) ? &pcaA : &pcaB;
  bool have = (f < 8) ? havePcaA : havePcaB;
  if (!have) return;
  p->setPin(chan, in1, false);
  p->setPin(chan + 1, in2, false);
#endif
}
static void motorOff(uint8_t f) { motorRaw(f, 0, 0); }  // coast

static void motorDrive(uint8_t f, float effort) {
  // effort in [-1, 1]; map through the stiction floor so small efforts move.
  if (effort == 0) { motorOff(f); return; }
  uint16_t mag = (uint16_t)(PWM_MIN_MOVE + fabsf(effort) * (PWM_MAX - PWM_MIN_MOVE));
  if (mag > PWM_MAX) mag = PWM_MAX;
  if (effort > 0) motorRaw(f, mag, 0);
  else            motorRaw(f, 0, mag);
}

// --------------------------------------------------------------------------- //
// subsystem tasks
// --------------------------------------------------------------------------- //
static void taskControl() {           // PID_HZ
  static const float dt = 1.0f / PID_HZ;
  for (uint8_t f = 0; f < NUM_FADERS; f++) {
    uint16_t raw = readMux(f);
    Fader& fd = faders[f];
    fd.pos += 0.5f * ((float)raw - fd.pos);        // light EMA filter

    if (fd.touched || fd.target < 0) {
      motorOff(f);
      uint16_t p = (uint16_t)fd.pos;
      if (abs((int)p - (int)fd.lastReported) > REPORT_DELTA) {
        emit("FADER", f, p);
        fd.lastReported = p;
      }
      fd.prevErr = 0;
      continue;
    }
    float err = (float)fd.target - fd.pos;
    if (fabsf(err) <= PID_DEADBAND) { motorOff(f); fd.prevErr = 0; continue; }
    float deriv = (err - fd.prevErr) / dt;
    fd.prevErr = err;
    float effort = (PID_KP * err + PID_KD * deriv) / (float)FADER_MAX;
    motorDrive(f, constrain(effort, -1.0f, 1.0f));
  }
  // balance pot
  uint16_t bal = readMux(MUX_CH_BALANCE);
  if (balanceLast == 0xFFFF || abs((int)bal - (int)balanceLast) > REPORT_DELTA) {
    emit("POT", 0, bal);
    balanceLast = bal;
  }
}

static void taskTouch() {             // ~100 Hz
#if HAS_MPR121
  if (!haveTouch) return;
  uint16_t t = touch.touched();
  for (uint8_t f = 0; f < NUM_FADERS; f++) {
    bool now = t & (1u << f);
    if (now != faders[f].touched) {
      faders[f].touched = now;
      if (now) motorOff(f);
      emit("TOUCH", f, now ? 1 : 0);
    }
  }
#endif
}

static void taskButtons() {           // ~200 Hz, 8 ms debounce
#if HAS_MCP23017
  if (!haveMcp) return;
  uint16_t gpio = mcp.readGPIOAB();
  uint32_t now = millis();
  if (buttonsLast == 0xFFFF) { buttonsLast = gpio; return; }
  for (uint8_t i = 0; i <= NUM_BUTTONS; i++) {   // 0-12 buttons; 15 = jack below
    if (i >= 16) break;
    bool was = !(buttonsLast & (1u << i));       // active-low (pull-ups)
    bool is  = !(gpio & (1u << i));
    if (was != is && now - buttonsChangedAt[i] > 8) {
      buttonsChangedAt[i] = now;
      if (i < NUM_BUTTONS) emit("BTN", i, is ? 1 : 0);
    }
  }
  bool jack = !(gpio & (1u << MCP_PIN_JACK));    // inserted = closed to GND
  if (jack != jackLast) {
    jackLast = jack;
    emit("JACK", 0, jack ? 1 : 0);
#if HAS_TPA2016
    if (haveAmp) amp.enableChannel(!jack, !jack);   // headphones in -> speakers off
#endif
  }
  buttonsLast = gpio;
#endif
}

static void pollEncoders() {          // every loop pass (fast)
  static const int8_t table[16] = {0,-1,1,0, 1,0,0,-1, -1,0,0,1, 0,1,-1,0};
  const uint8_t pinsA[2] = {PIN_ENC1_A, PIN_ENC2_A};
  const uint8_t pinsB[2] = {PIN_ENC1_B, PIN_ENC2_B};
  const uint8_t pinsS[2] = {PIN_ENC1_SW, PIN_ENC2_SW};
  const uint8_t btnIds[2] = {BTN_ENC1_PUSH, BTN_ENC2_PUSH};
  for (uint8_t e = 0; e < 2; e++) {
    uint8_t cur = (digitalRead(pinsA[e]) << 1) | digitalRead(pinsB[e]);
    if (cur != encPrev[e]) {
      encAccum[e] += table[(encPrev[e] << 2) | cur];
      encPrev[e] = cur;
    }
    bool sw = digitalRead(pinsS[e]);           // active low
    if (sw != encSwLast[e]) {
      encSwLast[e] = sw;
      emit("BTN", btnIds[e], sw ? 0 : 1);
    }
  }
}

static void taskEncoderReport() {     // ~20 Hz: 4 steps = 1 detent on EC11/PEC11
  for (uint8_t e = 0; e < 2; e++) {
    int8_t detents = encAccum[e] / 4;
    if (detents != 0) {
      encAccum[e] -= detents * 4;
      emit("ENC", e, detents);
    }
  }
}

static void taskBattery() {           // every 5 s
#if HAS_MAX17040
  Wire.beginTransmission(ADDR_MAX17040);
  Wire.write(0x04);                              // SOC register
  if (Wire.endTransmission(false) != 0) return;  // gauge absent — stay quiet
  if (Wire.requestFrom((int)ADDR_MAX17040, 2) != 2) return;
  uint8_t hi = Wire.read(), lo = Wire.read();
  uint16_t socX10 = (uint16_t)hi * 10 + ((uint16_t)lo * 10) / 256;
  if (socX10 > 1000) socX10 = 1000;
  emit("BAT", 0, socX10);
  emit("CHG", 0, digitalRead(PIN_X728_PLD) ? 1 : 0);
#endif
}

static void taskDisplay() {           // ~10 Hz
#if HAS_OLED
  if (!haveOled) return;
  // live position estimate between DISP TIME updates
  uint32_t pos = dispPosMs;
  if (dispDurMs > 0 && dispPosStamp) pos += millis() - dispPosStamp;
  if (dispDurMs > 0 && pos > dispDurMs) pos = dispDurMs;

  char timeStr[12];
  snprintf(timeStr, sizeof(timeStr), "%lu:%02lu",
           (unsigned long)(pos / 60000), (unsigned long)((pos / 1000) % 60));

  oled.clearBuffer();
  oled.setFont(u8g2_font_logisoso28_tn);          // big elapsed time
  oled.drawStr(0, 32, timeStr);

  oled.setFont(u8g2_font_7x13B_tr);               // scrolling title
  int16_t tw = oled.getStrWidth(dispTitle);
  if (tw <= 256) {
    oled.drawStr(0, 60, dispTitle);
  } else {
    marqueeX -= 2;
    if (marqueeX < -(tw + 40)) marqueeX = 0;
    oled.drawStr(marqueeX, 60, dispTitle);
    oled.drawStr(marqueeX + tw + 40, 60, dispTitle);
  }
  if (dispKbps) {                                 // stream info, top right
    char info[24];
    snprintf(info, sizeof(info), "%uk %ukHz", dispKbps, dispKhz);
    oled.setFont(u8g2_font_6x10_tr);
    oled.drawStr(256 - oled.getStrWidth(info), 10, info);
  }
  oled.sendBuffer();
#endif
}

// --------------------------------------------------------------------------- //
// setup / loop
// --------------------------------------------------------------------------- //
void setup() {
  Serial.begin(115200);

  pinMode(PIN_PCA_OE, OUTPUT);
  digitalWrite(PIN_PCA_OE, HIGH);      // motors DISABLED until PCA configured
  pinMode(PIN_X728_PLD, INPUT_PULLUP);
  for (uint8_t i = 0; i < 4; i++) pinMode(PIN_MUX_S[i], OUTPUT);
  analogReadResolution(10);
  const uint8_t encPins[6] = {PIN_ENC1_A, PIN_ENC1_B, PIN_ENC1_SW,
                              PIN_ENC2_A, PIN_ENC2_B, PIN_ENC2_SW};
  for (uint8_t i = 0; i < 6; i++) pinMode(encPins[i], INPUT_PULLUP);

  Wire.begin();                        // GP4/GP5
  Wire.setClock(400000);

#if HAS_PCA9685
  havePcaA = pcaA.begin();
  havePcaB = pcaB.begin();
  for (uint8_t p = 0; p < 2; p++) {
    Adafruit_PWMServoDriver* d = p ? &pcaB : &pcaA;
    if (!(p ? havePcaB : havePcaA)) continue;
    d->setOscillatorFrequency(27000000);
    d->setPWMFreq(1526);               // max — least audible motor buzz
    for (uint8_t c = 0; c < 16; c++) d->setPin(c, 0, false);
  }
  if (havePcaA || havePcaB) digitalWrite(PIN_PCA_OE, LOW);   // outputs now safe
  logmsg(havePcaA ? "pcaA ok" : "pcaA MISSING");
  logmsg(havePcaB ? "pcaB ok" : "pcaB MISSING");
#endif
#if HAS_MPR121
  haveTouch = touch.begin(ADDR_MPR121, &Wire);
  logmsg(haveTouch ? "mpr121 ok" : "mpr121 MISSING");
#endif
#if HAS_MCP23017
  haveMcp = mcp.begin_I2C(ADDR_MCP23017, &Wire);
  if (haveMcp)
    for (uint8_t i = 0; i < 16; i++) mcp.pinMode(i, INPUT_PULLUP);
  logmsg(haveMcp ? "mcp23017 ok" : "mcp23017 MISSING");
#endif
#if HAS_TPA2016
  haveAmp = amp.begin(ADDR_TPA2016, &Wire);
  if (haveAmp) { amp.enableChannel(true, true); amp.setGain(6); }
  logmsg(haveAmp ? "tpa2016 ok" : "tpa2016 MISSING");
#endif
#if HAS_NEOPIXEL
  pixels.begin();
  pixels.clear();
  pixels.show();
#endif
#if HAS_OLED
  haveOled = oled.begin();
  logmsg(haveOled ? "oled ok" : "oled MISSING");
#endif
  logmsg("winamp-fw ready");
}

void loop() {
  static uint32_t tControl = 0, tTouch = 0, tButtons = 0, tEncRep = 0,
                  tDisplay = 0, tBattery = 0;
  uint32_t now = millis();

  pollSerial();
  pollEncoders();                                 // every pass — quadrature

  if (now - tControl >= (1000 / PID_HZ)) { tControl = now; taskControl(); }
  if (now - tTouch   >= 10)   { tTouch = now;   taskTouch(); }
  if (now - tButtons >= 5)    { tButtons = now; taskButtons(); }
  if (now - tEncRep  >= 50)   { tEncRep = now;  taskEncoderReport(); }
  if (now - tDisplay >= 100)  { tDisplay = now; taskDisplay(); }
  if (now - tBattery >= 5000) { tBattery = now; taskBattery(); }
}

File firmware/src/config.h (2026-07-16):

// WinAmp Physical Edition — RP2040 firmware configuration.
// Pin assignments mirror hardware/diagrams/pico-pinout.svg — keep them in sync.
#pragma once

#include <Arduino.h>

// ---- feature flags (disable subsystems during bench bring-up) -------------- //
#define HAS_PCA9685   1   // motor PWM (2x, I2C)
#define HAS_MPR121    1   // fader touch-sense
#define HAS_MCP23017  1   // panel buttons + jack detect
#define HAS_TPA2016   1   // speaker amp
#define HAS_MAX17040  1   // X728 fuel gauge (jumpered onto our I2C bus)
#define HAS_OLED      1   // SSD1322 256x64 readout
#define HAS_NEOPIXEL  1

// ---- pins (see pico-pinout.svg) -------------------------------------------- //
// I2C0 (Wire) uses the arduino-pico defaults: SDA=GP4, SCL=GP5.
static const uint8_t PIN_X728_PLD   = 2;    // X728 AC-loss / charge detect
static const uint8_t PIN_PCA_OE     = 3;    // PCA9685 /OE — HIGH = motors disabled
static const uint8_t PIN_MUX_S[4]   = {6, 7, 8, 9};
static const uint8_t PIN_OLED_SCK   = 10;   // software SPI
static const uint8_t PIN_OLED_MOSI  = 11;
static const uint8_t PIN_OLED_DC    = 12;
static const uint8_t PIN_OLED_CS    = 13;
static const uint8_t PIN_OLED_RST   = 14;
static const uint8_t PIN_ENC1_A     = 16;
static const uint8_t PIN_ENC1_B     = 17;
static const uint8_t PIN_ENC1_SW    = 18;
static const uint8_t PIN_ENC2_A     = 19;
static const uint8_t PIN_ENC2_B     = 20;
static const uint8_t PIN_ENC2_SW    = 21;
static const uint8_t PIN_NEOPIXEL   = 22;
static const uint8_t PIN_MUX_ADC    = 26;   // ADC0 <- mux common

// ---- I2C addresses (see hardware/wiring.md address map) -------------------- //
static const uint8_t ADDR_PCA_A     = 0x40; // motors 0-7 (channels 0-15)
static const uint8_t ADDR_PCA_B     = 0x41; // motors 8-9 (channels 0-3)
static const uint8_t ADDR_MCP23017  = 0x20;
static const uint8_t ADDR_MAX17040  = 0x36;
static const uint8_t ADDR_TPA2016   = 0x58;
static const uint8_t ADDR_MPR121    = 0x5A;

// ---- controls --------------------------------------------------------------- //
static const uint8_t NUM_FADERS     = 10;   // 0-6 EQ, 7 preamp, 8 volume, 9 seek
static const uint8_t NUM_BUTTONS    = 13;   // ButtonId 0-12 on MCP pins 0-12
static const uint8_t MCP_PIN_JACK   = 15;   // headphone jack detect (switched TRS)
static const uint8_t BTN_ENC1_PUSH  = 13;   // encoder pushes emit these button ids
static const uint8_t BTN_ENC2_PUSH  = 14;
static const uint8_t MUX_CH_BALANCE = 10;   // wipers 0-9 = faders, 10 = balance pot
static const uint8_t NUM_PIXELS     = 8;

// ---- tuning ----------------------------------------------------------------- //
static const uint16_t FADER_MAX     = 1023; // protocol position range
static const uint16_t PID_HZ        = 250;  // control loop rate
static const float    PID_KP        = 3.0f; // effort per count of error (tune!)
static const float    PID_KD        = 0.8f;
static const uint16_t PID_DEADBAND  = 8;    // counts — close enough, motor off
static const uint16_t REPORT_DELTA  = 5;    // counts — user-move report threshold
static const uint16_t PWM_MAX       = 4095; // PCA9685 full scale
static const uint16_t PWM_MIN_MOVE  = 900;  // stiction floor (tune on bench)

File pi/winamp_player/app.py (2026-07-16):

"""Application entry point: main loop, action routing, motor sync.

Responsibilities:
  * poll the playback backend and physical controls
  * route semantic actions (from the UI or the microcontroller) to the backend
  * drive the motorized faders back toward the current state (the magic bit:
    the seek fader physically follows the song, volume follows volume, EQ
    faders snap to the active preset) — unless the user is touching them.
"""

from __future__ import annotations

import sys
import threading
import time

import pygame

from .config import Config
from .controls import (
    ButtonId,
    ControlEvent,
    ControlEventType,
    FaderId,
    FADER_MAX,
    cmd_disp_time,
    cmd_disp_title,
    cmd_fader_target,
    make_controls,
)
from .images import ImageCache
from .library import BrowseState, make_library
from .models import EQ_BANDS, PlaybackStatus
from .power import make_battery
from .spotify import make_backend
from .spotify_web import make_web
from .ui.screen import ScreenUI


class App:
    def __init__(self, cfg: Config) -> None:
        self.cfg = cfg
        pygame.init()
        pygame.display.set_caption("WinAmp · Physical Edition")
        flags = pygame.FULLSCREEN if cfg.fullscreen else 0
        self.surface = pygame.display.set_mode(cfg.window_size, flags)
        if cfg.fullscreen:
            pygame.mouse.set_visible(False)   # touch kiosk — no cursor
        self.clock = pygame.time.Clock()

        # One shared Web API client feeds both playback (webapi backend) and browsing.
        self.web = make_web(cfg)
        self.backend = make_backend(cfg, self.web)
        self.controls = make_controls(cfg)

        # Browsing (real Spotify playlists) + async album art.
        self.images = ImageCache()
        self.screen = ScreenUI(self.surface, self.on_action, self.images)
        self.browse = BrowseState()
        self.library, msg = make_library(self.web)
        if self.library is not None:
            self.browse.loading = True
            self.library.start()
        else:
            print(f"[library] {msg} — using demo playlist")

        self.battery = make_battery(cfg)
        self._battery_accum = 99.0           # read on first frame

        self._grabbed: set[int] = set()      # fader ids the user is touching
        self._last_sent: dict[int, int] = {}  # last target per fader (avoid spam)
        self.running = True

        # Populate the Up Next view for real-playback backends that don't fetch
        # the queue themselves (librespot) — poll the Web API queue off-thread.
        # (Mock playback shows its own playlist; polling the account's real
        # queue there would mismatch what's "playing".)
        if (self.web is not None
                and getattr(self.backend, "real_playback", False)
                and not getattr(self.backend, "populates_queue", False)):
            threading.Thread(target=self._queue_loop, daemon=True).start()

    def _queue_loop(self) -> None:
        while self.running:
            try:
                self.backend.state.queue = self.web.queue()
            except Exception:  # noqa: BLE001
                pass
            time.sleep(4.0)

    # ------------------------------------------------------------------ #
    # action routing (shared by mouse UI and physical controls)
    # ------------------------------------------------------------------ #
    def on_action(self, action: str, **kw) -> None:
        b, st = self.backend, self.backend.state
        if action == "play":
            if st.status is not PlaybackStatus.PLAYING:
                b.play_pause()
        elif action == "play_pause":
            b.play_pause()
        elif action == "stop":
            b.stop()
        elif action == "next":
            b.next()
        elif action == "prev":
            b.prev()
        elif action == "set_view":
            self.screen.set_view(kw["name"])
        elif action == "show_library":       # legacy alias -> Playlists view
            self.screen.set_view("playlists")
        elif action == "open_playlist":
            self._open_playlist(kw["index"])
            self.screen.set_view("now_playing")
        elif action == "seek":
            b.seek(kw["position_ms"])
        elif action == "set_volume":
            b.set_volume(kw["volume"])
        elif action == "set_eq_band":
            b.set_eq_band(kw["band"], kw["gain_db"])
        elif action == "set_preamp":
            st.eq_preamp = max(-12.0, min(12.0, kw["gain_db"]))
        elif action == "select_track":
            b.select_track(kw["index"])
        elif action == "toggle_shuffle":
            b.toggle_shuffle()
        elif action == "cycle_repeat":
            b.cycle_repeat()

    # ------------------------------------------------------------------ #
    # library browsing
    # ------------------------------------------------------------------ #
    def _open_playlist(self, index: int) -> None:
        if not (0 <= index < len(self.browse.playlists)):
            return
        pl = self.browse.playlists[index]
        if getattr(self.backend, "real_playback", False):
            # Play the playlist directly on the device — works for owned AND
            # followed playlists (no tracklist read needed; the Up Next view
            # shows the live queue). This is the on-device path.
            self.backend.play_context(pl.uri)
        elif self.library and pl.owned:
            # Mock/dev: load the tracklist so there's something to simulate.
            self.library.open_playlist(pl)

    def _pump_library(self) -> None:
        if not self.library:
            return
        for kind, payload in self.library.poll():
            if kind == "playlists":
                self.browse.playlists = payload
                self.browse.loading = False
                # prefetch playlist thumbnails so the list looks alive fast
                for pl in payload:
                    if pl.image_url:
                        self.images.get(pl.image_url, (40, 40))
            elif kind == "tracks":
                playlist, tracks = payload
                if tracks:  # mock path only; empty playlists just stay put
                    self.backend.load_tracks(tracks, context_uri=playlist.uri)
            elif kind == "error":
                self.browse.error = str(payload)
                self.browse.loading = False
                print(f"[library] {payload}")
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

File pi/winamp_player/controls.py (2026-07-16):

"""Physical controls bridge (Pi side).

The microcontroller owns all the physical I/O and the real-time motor loops.
The Pi talks to it over a newline-delimited ASCII serial protocol — chosen over
binary because it's trivial to debug with a serial monitor.

This module defines the protocol, an event model, and two sources:

* ``MockControls`` — yields nothing; the on-screen UI provides input instead.
* ``SerialControls`` — reads/writes the real link to the microcontroller.

The canonical protocol spec lives in docs/serial-protocol.md. Keep the two in
sync (and the mirror in firmware/src/main.cpp).
"""

from __future__ import annotations

from dataclasses import dataclass
from enum import Enum
from typing import Iterator, Protocol


class ControlEventType(Enum):
    BUTTON = "BTN"     # id, pressed(0/1)
    FADER = "FADER"    # id, position(0..1023) — user moved a fader
    TOUCH = "TOUCH"    # id, touched(0/1) — user grabbed a motorized fader
    ENCODER = "ENC"    # id, delta(int)
    POT = "POT"        # id, value(0..1023)
    BATTERY = "BAT"    # 0, state-of-charge ×10 (0..1000) from the X728 gauge
    CHARGING = "CHG"   # 0, on-AC/charging(0/1)
    JACK = "JACK"      # 0, headphones inserted(0/1) — firmware mutes the amp


# Stable control ids. Faders are the motorized ones the Pi commands back.
class FaderId(Enum):
    EQ0 = 0
    EQ1 = 1
    EQ2 = 2
    EQ3 = 3
    EQ4 = 4
    EQ5 = 5
    EQ6 = 6
    PREAMP = 7
    VOLUME = 8
    SEEK = 9


class ButtonId(Enum):
    PREV = 0
    PLAY = 1
    PAUSE = 2
    STOP = 3
    NEXT = 4
    EJECT = 5
    SHUFFLE = 6
    REPEAT = 7
    EQ_TOGGLE = 8
    # Dedicated view-switch buttons for the central screen (one per view).
    VIEW_NOW_PLAYING = 9
    VIEW_PLAYLISTS = 10
    VIEW_QUEUE = 11
    # Cycles EQ presets — the faders physically animate into each curve.
    EQ_PRESET = 12
    # Rotary-encoder push switches (wired to the Pico directly, not the MCP).
    ENC1_PUSH = 13
    ENC2_PUSH = 14


class PotId(Enum):
    """Non-motorized analog controls, reported as ``EV POT <id> <value>``."""

    BALANCE = 0


FADER_MAX = 1023  # 10-bit ADC range on the microcontroller


@dataclass(frozen=True)
class ControlEvent:
    type: ControlEventType
    id: int
    value: int


def parse_event(line: str) -> ControlEvent | None:
    """Parse one inbound line: ``EV <TYPE> <id> <value>``. Returns None if junk."""
    parts = line.strip().split()
    if len(parts) != 4 or parts[0] != "EV":
        return None
    try:
        etype = ControlEventType(parts[1])
        return ControlEvent(etype, int(parts[2]), int(parts[3]))
    except (ValueError, KeyError):
        return None


def cmd_fader_target(fader: FaderId, position: int) -> str:
    """Drive a motorized fader to a target position (0..FADER_MAX)."""
    position = max(0, min(FADER_MAX, int(position)))
    return f"FADER {fader.value} {position}\n"


def cmd_fader_release(fader: FaderId) -> str:
    """Cut motor power so the user can move the fader freely."""
    return f"FADER_RELEASE {fader.value}\n"


def cmd_led(index: int, r: int, g: int, b: int) -> str:
    return f"LED {index} {r} {g} {b}\n"


# The RP2040 drives the retro amber OLED readout strip (time / title / stream
# info). The Pi streams display state with these commands; text is a single
# line, no newlines (the terminator is the protocol frame).
def cmd_disp_title(text: str) -> str:
    return f"DISP TITLE {_one_line(text)}\n"


def cmd_disp_time(position_ms: int, duration_ms: int) -> str:
    return f"DISP TIME {int(position_ms)} {int(duration_ms)}\n"


def cmd_disp_info(kbps: int, khz: int) -> str:
    return f"DISP INFO {int(kbps)} {int(khz)}\n"


def _one_line(text: str) -> str:
    return " ".join(str(text).split()) or "-"


class ControlsSource(Protocol):
    def read_events(self) -> Iterator[ControlEvent]: ...
    def send(self, command: str) -> None: ...
    def close(self) -> None: ...


class MockControls:
    """No hardware: the on-screen widgets provide input instead."""

    def read_events(self) -> Iterator[ControlEvent]:
        return iter(())

    def send(self, command: str) -> None:  # swallow motor commands
        pass

    def close(self) -> None:
        pass


class SerialControls:
    """Real microcontroller link over USB serial (pyserial)."""

    def __init__(self, port: str, baud: int) -> None:
        import serial  # lazy import so mock mode needs no pyserial

        self._ser = serial.Serial(port, baud, timeout=0)
        self._buf = b""

    def read_events(self) -> Iterator[ControlEvent]:
        self._buf += self._ser.read(4096)
        while b"\n" in self._buf:
            line, self._buf = self._buf.split(b"\n", 1)
            ev = parse_event(line.decode("ascii", "ignore"))
            if ev is not None:
                yield ev

    def send(self, command: str) -> None:
        self._ser.write(command.encode("ascii"))

    def close(self) -> None:
        self._ser.close()


def make_controls(cfg) -> ControlsSource:
    if cfg.controls == "serial":
        return SerialControls(cfg.serial_port, cfg.serial_baud)
    return MockControls()

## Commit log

2026-07-15 ci: GitHub Actions — lint, byte-compile, headless import smoke test
    Runs on push/PR to main and dev. The import smoke test loads every module
    under a dummy SDL driver, catching import/syntax errors without a display.
2026-07-15 feat(ui): show "Up Next" queue in the now-playing view
    Adds SpotifyWeb.queue() (GET /me/player/queue) and renders an UP NEXT list in
    the now-playing view. This gives a tracklist for anything playing — including
    followed/editorial playlists whose items Dev Mode won't let us read, and
    playback started on another device. Queue is fetched off the UI thread (~4s).
    [models.py, spotify.py, spotify_web.py]
2026-07-16 feat(ui): square multi-view screen UI (Now Playing / Playlists / Up Next)
    Replaces the temporary full-window WinAmp skin with the real device UI: a compact
    720x720 multi-view app for the HyperPixel Square. One view at a time — Now Playing
    (art, title, progress), Playlists (your library), Up Next (queue) — with a bottom
    tab strip. Views switch via dedicated physical buttons on the device (serial ->
    set_view); tabs / keys 1-2-3 / Tab in dev. Transport/EQ/faders are hardware, off
    the screen. Icons are drawn shapes (no unreliable glyph fonts). Removes display.py.
    Validated by rendering each view to PNG. Closes the multi-view UI redesign issue.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
    [app.py, config.py]
2026-07-16 fix(pi): librespot position/volume + Up Next queue on-device
    - LibrespotPlayer read live position from track.position (not a nonexistent
    top-level field) — fixes the stuck 0:00 progress bar. Volume now scales by
    volume_steps (go-librespot uses 0-100, not 0-65535). Throttle /status polling
    to ~3/s with local position interpolation for a smooth bar.
    - App polls the Web API queue off-thread for backends that don't fetch it
    themselves (librespot), so the Up Next view populates on the device.
    [app.py, spotify.py]
2026-07-16 fix(pi): play playlists on click (librespot) + honest track-count display
    - _open_playlist: for real-playback backends, play the playlist directly by
    context URI (works for owned + followed); no tracklist read needed since the
    Up Next view shows the live queue. Fixes "clicking a playlist does nothing".
    - Playlists view: Dev Mode strips track counts from /me/playlists (tracks=null),
    so show "tap to play" instead of a bogus "0 tracks".
    [app.py]
2026-07-16 chore(deploy): capture HyperPixel kiosk setup + hide cursor in fullscreen
    - deploy/winamp-kiosk.{sh,service}: the systemd user service + launcher that
    autostart the UI on boot, wait for the Wayland socket, and rotate the panel
    180 at the compositor level (so touch follows the display).
    - app: hide the mouse cursor when fullscreen (touch kiosk).
    - docs/pi-bringup.md: HyperPixel 4.0 Square overlay + kiosk autostart, incl. the
    KMS-rotate-breaks-touch and labwc-autostart gotchas.
2026-07-16 docs(hw): wiring + layout schematics (SVG)
    Three diagrams in hardware/diagrams/, embedded in wiring.md:
    - system-wiring.svg — full power/data topology (battery→UPS→Pi, USB to
    RP2040 + DAC, the I2C expander bus out to the 10 motorized faders)
    - pico-pinout.svg — every RP2040 pin assignment (19/26 used, spares marked)
    - front-panel.svg — to-scale (4 px/mm) panel layout with dimensions
    Drawing the panel to scale surfaced a real finding: 60 mm fader travel pushes
    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
2026-07-16 docs(hw): vendor parts list, datasheet fetch kit, enclosure design notes
    - hardware/PARTS.md: buyable shopping list — Adafruit cart (~$128, PCA9685
    price spot-verified), DigiKey for the ALPS RS60N11M9A0F faders (buy 1, test,
    then 9; RSA0N=100mm warning), Geekworm X728, battery-house 18650s, SSD1322
    OLED options. Suggested order-of-orders.
    - hardware/datasheets/: fetch.sh downloads all 14 datasheets (PDFs gitignored —
    manufacturer copyright; script keeps it reproducible) + an index with key
    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
2026-07-16 feat(hw): internal speakers + amp; Sonos via Connect transfer, BT via Pi radio
    Standalone playback, headphones optional:
    - TPA2016 stereo Class-D amp (I2C — 5th device on the RP2040 expander bus,
    firmware gain/AGC/mute) + enclosed stereo speaker pair (sealed backs, fit the
    32mm depth) + switched headphone jack (insert detect -> MCP23017 -> amp mute).
    - External outputs need NO new hardware: Sonos & co. via Spotify Connect
    transfer (Web API transfer_to already exists — output picker view, #56); BT
    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
2026-07-16 feat(firmware): full RP2040 build-out — compiles clean, ready for bench
    Complete firmware replacing the skeleton (desk-written; hardware-untested):
    - config.h: all pins/addresses/tuning in one place + HAS_* feature flags for
    one-subsystem-at-a-time bring-up; missing I2C boards degrade with a LOG.
    - Per-fader PID vs PCA9685->DRV8833 (stiction floor, deadband, EMA filter),
    motor-safe boot (/OE held until channels zeroed), MPR121 touch gating.
    - MCP23017 buttons (debounced) + headphone jack detect -> TPA2016 auto-mute;
    quadrature encoders (detent-accurate) with push switches as BTN 13/14.
    - SSD1322 OLED readout: big elapsed time (interpolated between DISP TIME
    updates), marquee title,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
    [app.py, config.h, controls.py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]
2026-07-16 feat(cad): Concept B layout — 225mm / 10-band EQ / offset screen / pot column
    Exploration per the paper-test feedback: full classic 10-band+preamp bank,
    screen offset left with view buttons on its edge, large speaker grille field,
    4-pot side column. Passes all geometry checks; I/O fits (22/32 PWM, 11/12
    touch, 14/16 mux). Committed for a 1:1 paper print; formalize if chosen.
    [concept-b.dxf]
2026-07-17 feat(cad): Concept E — the sketch at A proportions, screen as centerpiece
    185x295 (A's proportions, touch bigger), screen floated as the dominant element
    with an engraved accent frame, quiet right strip (grille + 2x2 pots), view-key
    stack top-right, 6-button transport, function row, full-width seek, and A's
    8-fader bank spread at 21mm pitch. Pure layout - no BOM/firmware/IO change.
    Front-runner pending 1:1 paper test.
    [concept-e.dxf]
2026-07-17 fix(docs): remove stale pre-findings front-panel sketch
    hardware/diagrams/front-panel.svg was the old concept sketch (pre-datasheet
    findings: wrong pitch, obsolete 165mm note) and could be mistaken for the
    final design. Removed; wiring.md now embeds the authoritative cad/front-panel
    drawing (A: 175x280, preamp + 7 bands).
2026-07-17 chore(parts): match the actually-built Adafruit cart
    Live-verified against adafruit.com (2026-07-17): drop design-removed rows
    (encoders, NeoPixel, 45mm pot), record OOS substitutions (Pico -> source
    elsewhere; 1669 stereo set -> 2x 3351 mono; 571 3-pack -> 1609 singles x3) and
    observed prices (DRV8833 $5.95, buttons $2.50/pk). Cart subtotal $61.15.
